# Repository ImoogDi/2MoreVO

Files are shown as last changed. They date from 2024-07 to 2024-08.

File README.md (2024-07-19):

#  2MoreVO
 Eurorack Dual VCO using the public CEM3340/AS3340 chip.

**Table of Contents**

- [Introduction](#intro)
- [Construction Guide](./doc/constructionguide.md)
- [Calibration](./doc/calibration.md)
- [Technical data](#technical-data)
- [References](#references)
- [License](#license)

## Introduction

This eurorack-modul is designed for modular-synthesizers as dual Voltage Controlled Oscillator.  
The oszillators are build around two IC's: <u>AS3340</u>, a clone of that wellknown CEM3340.  
Another benifit is the <u>three cannel VCA: AS3363</u> included to control the modulation-level, waveform output of VCO1 and oscillator-signal fading between VCO1- and VCO2-outputs.  

The '2MoreVO'-PCB's are:  
- one main backplane ('Backplane'), holding all switches, pots, jacks and voltage-references.  
- two VCO-PCB's stacked on the 'Backplane'.  
- one another backplane-PCB ('Backplane_B') hodling the 'three cannel VCA', operational-amp's and the eurorack-connection stacked on the 'Backplane'.   

All parts are common available and DIY-friendly designed, most parts are SMD on the VCO-PCB's.   
(Details see attached pictures)  

- Modul Frontpanel

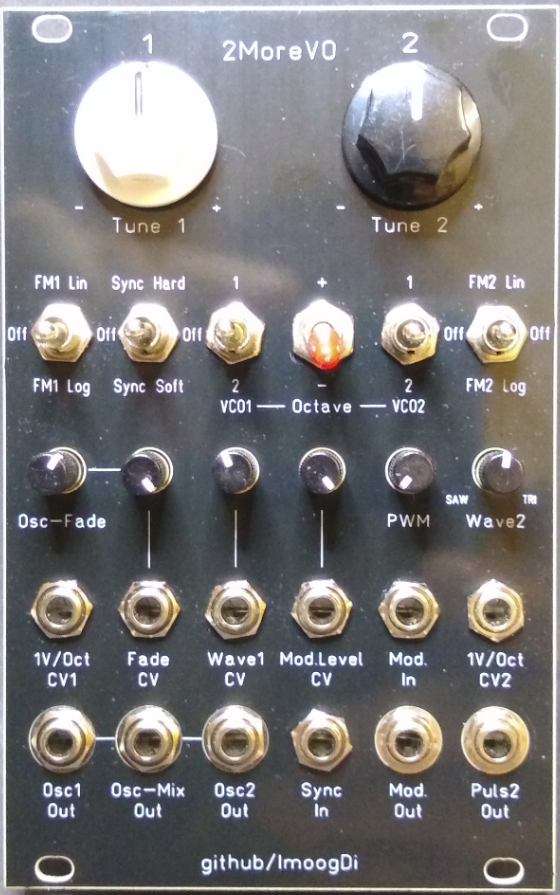
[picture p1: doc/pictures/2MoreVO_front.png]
Modul: 2MoreVO Front


<br>
- Modul Backpanel

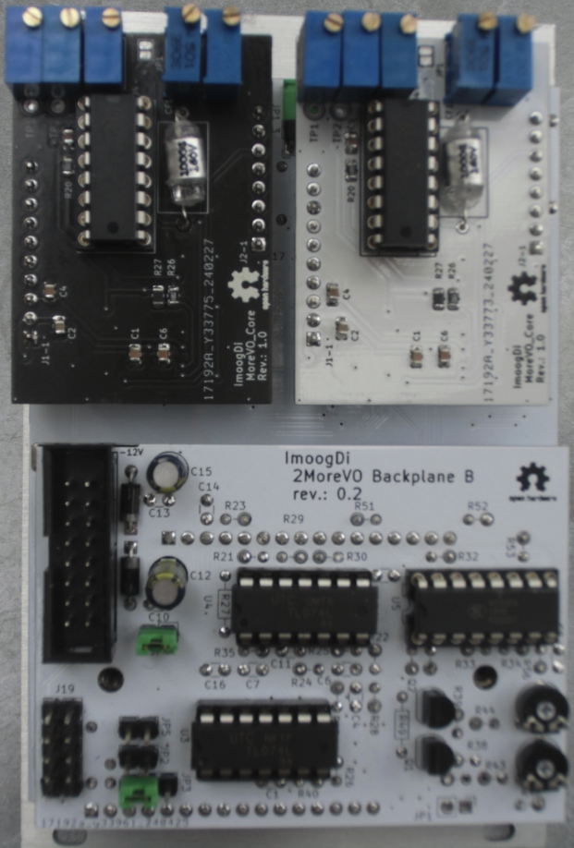
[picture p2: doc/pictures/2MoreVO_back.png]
Modul: 2MoreVO Backside


<br>
- Modul function-blocks

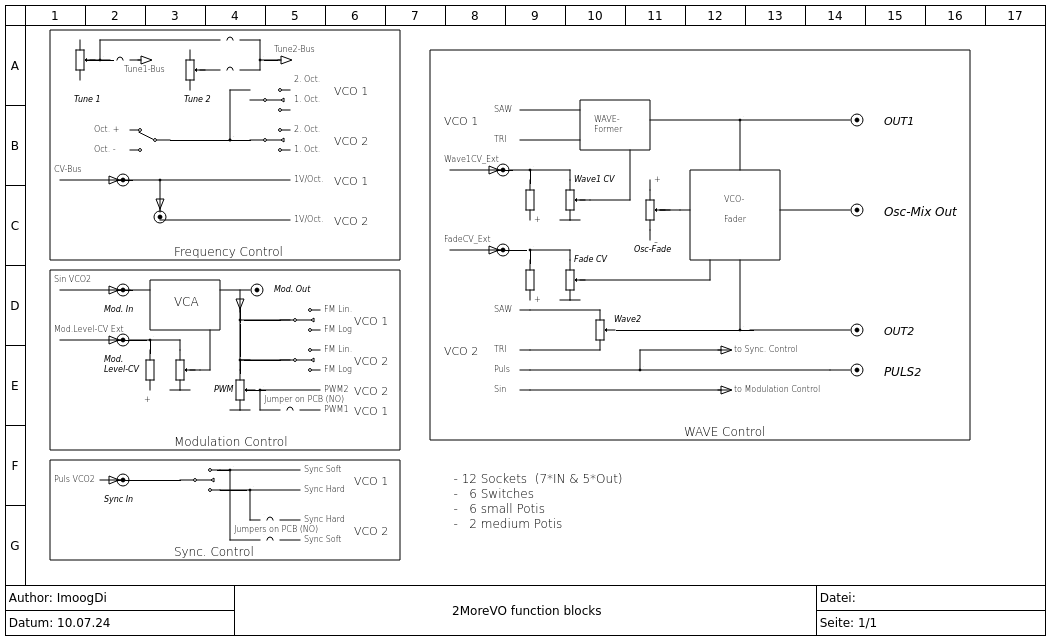
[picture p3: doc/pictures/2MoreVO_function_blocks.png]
Modul: 2MoreVO function blocks


<br>

<hr>
There are twelve 3.5mm jacks available for patching audio- and CV-signals.  

<table>
<tr>
    <th>Jack-Name</th>
    <th>Function</th>
    <th>Comment</th>
    <th>Detail</th>
</tr>
<tr>
    <td>1V/Oct CV1</td>
    <td>CV-input for VCO1 pitch control</td>
    <td>fixed 1Volt/Octave scaling</td>
    <td>This input is normalised with the eurobus Control-Voltage and connected with the '1V/Oct CV2' input.<br>Patch-cabel plugged in breaks the default connection to eurobus CV but the connection to '1V/Oct CV2' is still available.</td>
</tr>
<tr>
    <td>Fade CV</td>
    <td>CV-input for fading oscillator-signals</td>
    <td>The Fading between Osc1- and Osc2-signals on 'Osc-Mix Out' is controlled with this CV</td>
    <td>CV level adjustable between 0 ... max. with 'Fade CV'-pot.<br>works together with 'Osc-Fade'-pot.<hr>Bipolar signal input.</td>
</tr>
<tr>
    <td>Wave1 CV</td>
    <td>CV-input for VCO1 wave-control</td>
    <td>The waveform on 'Osc1 Out' is controlled with this CV</td>
    <td>CV Level adjustable between 0 ... max. with 'Wave1 CV'-pot.<hr>Bipolar signal input.</td>
</tr>
<tr>
    <td>Mod.Level CV</td>
    <td>CV-input for modulation level control</td>
    <td>Control of modulation level on 'Mod Out'</td>
    <td>Modulation Level adjustable between 0 ... max. with 'Mod.Level CV'-pot.<hr>Bipolar signal input.</td>
</tr>
<tr>
    <td>Mod. In</td>
    <td>Modulation signal input</td>
    <td>input for external signals controlling FM(Lin/Log) and PWM on Osc1 and Osc2</td>
    <td>This input is normalised with the sinusoidal-signal from Osc2 if no signal is plugged in.<hr>Bipolar signal input.</td>
</tr>
<tr>
    <td>1V/Oct CV2</td>
    <td>CV-input for VCO2 pitch control</td>
    <td>fixed 1Volt/Octave scaling</td>
    <td>This input is normalised with the '1V/Oct CV1' input.<br>Patch-cabel plugged in breaks the default connection to '1V/Oct CV1'.</td>
</tr>
<tr>
    <td>Osc1 Out</td>
    <td>output for VCO1-oscillator signal</td>
    <td>triangle- to saw-waveform output, morvable manually or with external CV</td>
    <td>Waveform morvable with 'Wave1 CV'-pot and CV-signal.</td>
</tr>
<tr>
    <td>Osc-Mix Out</td>
    <td>output for mixed VCO1-/VCO2-oscillator signal</td>
    <td>mixed signal from Osc1- and Osc2-outputs</td>
    <td>Waveforms fadeable between Osc1- and Osc2-signal outputs.<br>Fading can be done with 'Fade CV'-pot and CV-signal.<br>50%/50% Osc1/2-signal level on 'Osc-Mix Out', if 'Osc-Fade'-pot is in centerposition and no 'Fade CV' is plugged in.</td>
</tr>
<tr>
    <td>Osc2 Out</td>
    <td>output for VCO2-oscillator signal</td>
    <td>saw- to triangle-waveform output, morvable manually</td>
    <td>Waveform morvable with 'Wave2'-pot between saw- and triangle-signal.</td>
</tr>
<tr>
    <td>Sync In</td>
    <td>Sync-signal for VCO1 (optional VCO2)</td>
    <td>this signal can be switched to: 'Sync Hard', ' Sync Soft' or 'Off'</td>
    <td>This input is normalised with the 'Puls2 Out'-signal from VCO2.<br>Patch-cabel plugged in breaks the default connection to 'Puls2 Out'.</td>
</tr>
<tr>
    <td>Mod Out</td>
    <td>output for modulation-signal controllable with 'Mod.Level CV'</td>
    <td>modulation-signal used for 'FMx Lin/Log' and 'PWM'<br>default sinusoidal-signal from VCO2 used for VCO1 modulation</td>
    <td>sinusoidal-signal from VCO2 is available on this output if high impedance connection is used.<hr>optional an external low impedance signal plugged in can overwride the internal modulation.</td>
</tr>
<tr>
    <td>Puls2 Out</td>
    <td>output for puls-signal from VCO2</td>
    <td>output-signal for synchronisation and audio<br>the pulswith is controllable with 'PWM'-pot using the 'Mod Out'-signal</td>
    <td>This output is also internally linked to 'Sync In'.<hr>Bipolar output with +-5.0Volt level.</td>
</tr>
</table>
<br>

There are eight potentiometers with following functions:  

<table>
<tr>
    <th>Pot-Name</th>
    <th>Function</th>
    <th>Comment</th>
    <th>Detail</th>
</tr>
<tr>
    <td>Tune 1</td>
    <td>Pitch for VCO1</td>
    <td>default pitch in center-position</td>
    <td>tuning-range +-2 octaves.</td>
</tr>
<tr>
    <td>Tune 2</td>
    <td>Pitch for VCO2</td>
    <td>default pitch in center-position</td>
    <td>tuning-range +-2 octaves.</td>
</tr>
<tr>
    <td>Osc-Fade</td>
    <td>manually fading between Osc1- and Osc2-signals on 'Osc-Mix Out'</td>
    <td>works as CV offset for the 'Fade CV'-signal</td>
    <td>pot to CCW: Osc2-signal output.<br>pot to CW: Osc1-signal output.<br>pot to centerposition: equal level output.</td>
</tr>
<tr>
    <td>Fade CV</td>
    <td>CV Level amount pot for fading between Osc1- and Osc2-signals on 'Osc-Mix Out'</td>
    <td>works together with 'Osc-Fade' for fading Osc1/2-signals</td>
    <td>CV Level adjustable between 0 ... max.</td>
</tr>
<tr>
    <td>Wave1 CV</td>
    <td>CV Level amount pot for Osc1 waveform-selection on 'Osc1 out'</td>
    <td>manually selection of waveform is possible if no CV-signal is plugged in</td>
    <td>CV Level adjustable between 0 ... max.</td>
</tr>
<tr>
    <td>Mod.Level CV</td>
    <td>CV Level amount pot for modulation control</td>
    <td>manually modulationlevel control is possible if no CV-signal is plugged in</td>
    <td>CV Level adjustable between 0 ... max.</td>
</tr>
<tr>
    <td>PWM</td>
    <td>pulswith pot to control amount of PWM</td>
    <td>the modulation-signal on 'Mod Out' is used for PWM</td>
    <td>PWM amount adjustable between 0 ... max.<br>Pulswith is 50% on 'Puls2 Out' if pot is in CCW-position (set to 0).</td>
</tr>
<tr>
    <td>Wave2</td>
    <td>waveform selection pot for Osc2-signal</td>
    <td>manually morving between saw- and triangle-signal</td>
    <td>pot to CCW: SAW-signal.<br>pot to CW: Triangle-signal.<br>pot to centerposition: mixed signal.</td>
</tr>
</table>
<br>

There are six switches to control the behaviour of signals.  

<table>
<tr>
    <th>Switch</th>
    <th>Function</th>
    <th>Comment</th>
    <th>Detail</th>
</tr>
<tr>
    <td>FM1-switch</td>
    <td>switch for VCO1 FM modulation using signal on 'Mod Out'</td>
    <td>FM controll for VCO1</td>
    <td>FM1 Lin := Linear FM modulation.<br>Off := function off.<br>FM1 Log := Logarithmic FM modulation.</td>
</tr>
<tr>
    <td>Sync-switch</td>
    <td>switch for VCO1 Hard- or Soft-synchronisation with puls-signal from VCO2</td>
    <td>switched synchronisation-signal from 'Puls2 Out'</td>
    <td>Sync Hard := hard synced to VCO2.<br>Off := sync. function off.<br>Sync Soft := soft synced to VCO2.</td>
</tr>
<tr>
    <td>VCO1 Octave-switch</td>
    <td>switch for VCO1 pitch setting</td>
    <td>octaves up or down depending on 'Octave switch + or -'</td>
    <td>1 := one octave (up/down).<br>2 := two octaves (up/down).</td>
</tr>
<tr>
    <td>Octave up/down switch</td>
    <td>switch for VCO1- and VCO2-switched pitchcontrol</td>
    <td>selecting pitch up or down for VCO1 and VCO2</td>
    <td>+ :=  pitch up.<br>- := pitch down.</td>
</tr>
<tr>
    <td>VCO2 Octave-switch</td>
    <td>switch for VCO2 pitch setting</td>
    <td>octaves up or down depending on 'Octave switch + or -'</td>
    <td>1 := one octave (up/down).<br>2 := two octaves (up/down).</td>
</tr>
<tr>
    <td>FM2-switch</td>
    <td>switch for VCO2 FM modulation using signal on 'Mod Out'</td>
    <td>FM controll for VCO2</td>
    <td>FM1 Lin := Linear FM modulation.<br>Off := function off.<br>FM1 Log := Logarithmic FM modulation.</td>
</tr>
</table>
<br>
<hr>

## Technical data

- size:  
  width: 16HP  
  depth: 45mm

- power:  
    5Volt, 0 mA  
  +12Volt, 60mA  
  -12Volt, 60mA  

- frequency range: 20Hz to 20kHz.
- frequency CV scale: 1V/Oct on '1V/Oct CV1'- and '1V/Oct CV2'-inputs.
- frequency pot tuning range: +-2 Octaves.
- frequency switchable pitch range: plus or minus 1 or 2 octaves for oscillator 1/2.
- signal inputs, DC-coupled signal path.
- signal outputs, DC-coupled signal path.
- signal input impedance: > 50kOhm.
- signal output impedance: 500 Ohm.
- expandable with more '2MoreVO' dual-oscillator('s) used in master-/slave-configuration.

## References

* [electric druid, Single VCA crossfader](https://electricdruid.net/single-vca-crossfader/)
* [Tuning the AS3340](https://www.alfarzpp.lv/eng/sc/Tuning%20the%20AS3340.pdf)

## License
> Hardware:cc by-nc-sa 4.0  ([details](https://creativecommons.org/licenses/by-nc-sa/4.0/))

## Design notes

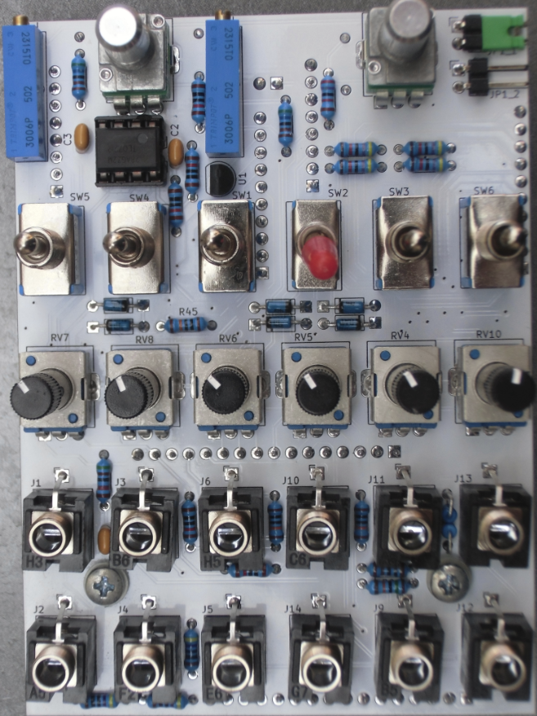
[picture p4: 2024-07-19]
doc/pictures/Backplane_top_mounted.png

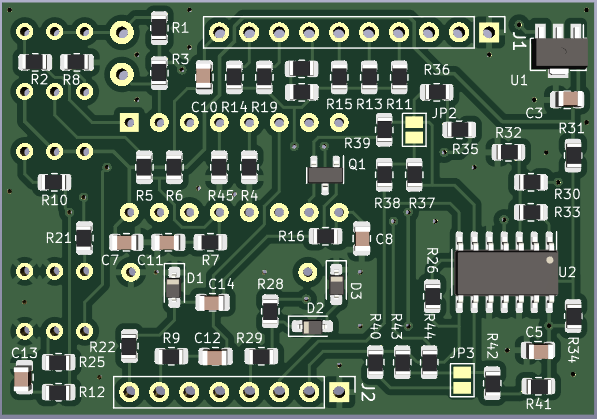
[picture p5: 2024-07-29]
doc/pictures/MoreVO_Core_bot_smds_only.png

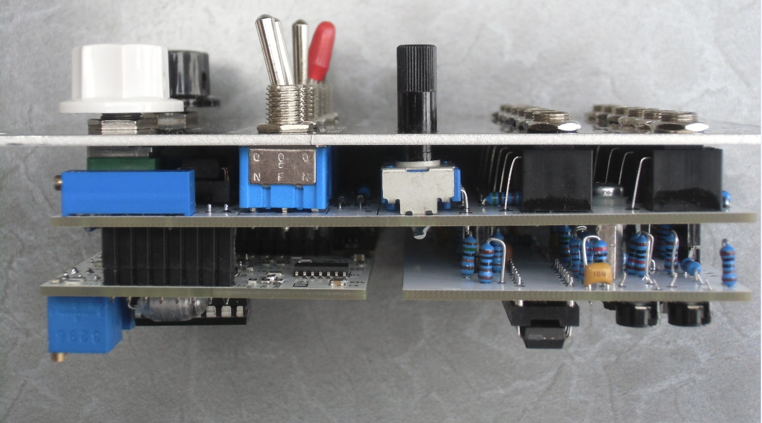
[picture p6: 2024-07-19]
doc/pictures/2MoreVO_left.png

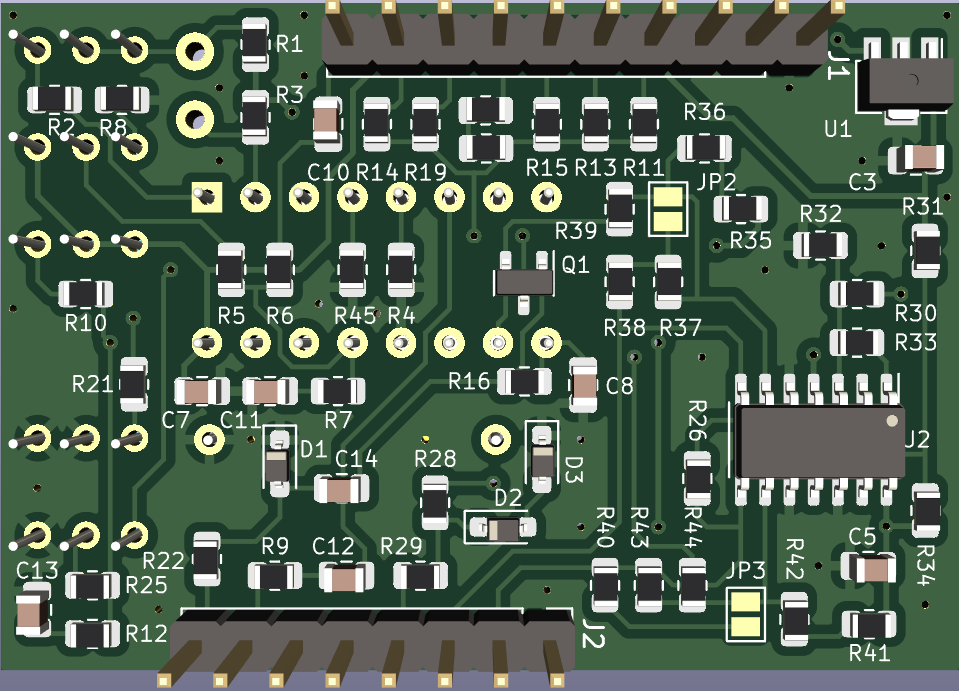
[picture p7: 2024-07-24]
doc/pictures/MoreVO_Core_PCB_bot.png

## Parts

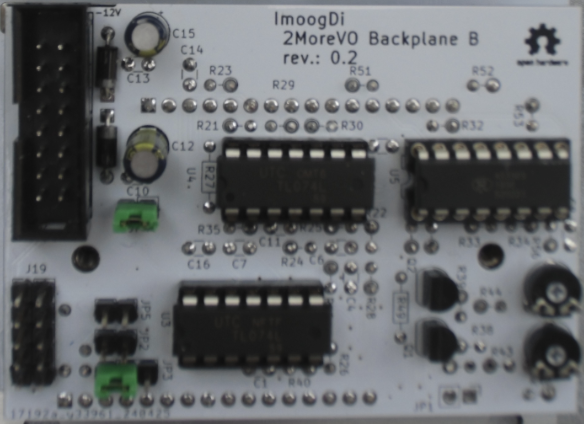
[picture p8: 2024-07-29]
doc/pictures/Backplane_B_bot_parts_mounted.png

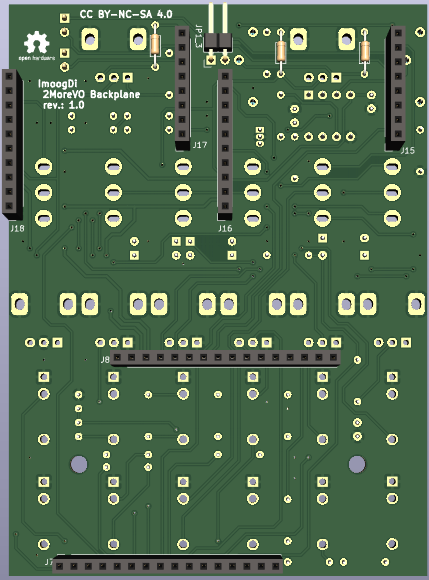
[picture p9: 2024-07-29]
doc/pictures/Backplane_bot_parts_mounted.png

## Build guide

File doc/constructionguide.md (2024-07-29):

#  2MoreVO
 Construction of CEM/AS3340 dual analog VCO eurorack-modul.

**Table of Contents**

- [Preconditions](#preconditions)
- [Construction](#construction)
- [First Switchon](#firstswitchon)
- [License](#license)

## Preconditions

- All PCB-Boards must be available:  
    1. Two 'MoreVO_Core'- PCB's. 
    2. One 'Backplane' - PCB. 
    3. One 'Backplane B' - PCB. 
- All BOM-parts must be available for PCB-Board 'MoreVO_Core', 'Backplane' and 'Backplane B' (see BOM-files: [MoreVO_Core](./../hw/MoreVO_Core/bom/MoreVO_Core.html) and [Backplane](./../hw/bom/2MoreVO_backplane.html)).
- The frontpanel is required for aligned soldering all pots, jacks and switches on PCB-Board 'Backplane'.

## Construction

### PCB-Board: 'MoreVO_Core' (two of them)

>#### 'MoreVO_Core' back side smd-parts (start soldering here!) [back side parts](./pictures/MoreVO_Core_PCB_bot.png)

> start soldering smd-parts on back side of Board: 'MoreVO_Core'.  

>- place all SMD resistors and capacitors to the back side. Watch the rigth alignment.
>- place all SMD diodes to the back side. Watch the rigth orientation and alignment.
>- place the LDO voltage-regulator U1 to the back side. Watch the rigth orientation and alignment.
>- place the transistor Q1 to the back side. Watch the rigth orientation and alignment.
>- place the quad opamp U2 to the back side. Watch the rigth orientation and alignment.
>- solder all parts on back side (reflow or by hand).
>- at least 'MoreVO_Core'-PCB back side should look like: [MoreVO_Core back side smd-parts (rev.: 1.1)](./pictures/MoreVO_Core_bot_smds_only.png) 

>#### 'MoreVO_Core' top side smd-parts [top side parts](./pictures/MoreVO_Core_PCB_top.png)

> continue soldering smd-parts on top side of Board: 'MoreVO_Core'.  

>- place all SMD resistors and capacitors to the top side. Watch the rigth alignment.
>- solder all parts on top side (by hand).
>- at least 'MoreVO_Core'-PCB top side should look like: [MoreVO_Core top side smd-parts (rev.: 1.1)](./pictures/MoreVO_Core_top_smds_only.png) 

>#### 'MoreVO_Core' <u>M</u>ounting<u>T</u>hrough<u>H</u>ole-parts [MTH-parts](./pictures/MoreVO_Core_PCB_top.png)

> continue soldering MTH-parts on back side of Board: 'MoreVO_Core'.  
>- fit the 10-position, 1 row header to the back side and solder it at the top side.  
>- fit the  8-position, 1 row header to the back side and solder it at the top side.  

> continue soldering MTH-parts on top side of Board: 'MoreVO_Core'.  
>- place one DIP16 socket at U4-position on top side. Watch the rigth orientation and solder it on back side.  
>- place all pots (RV1...RV5) on top side. Watch the rigth values and orientation and solder them on back side.  
>- at least place styrene capacitor CF1 on top side and solder it on back side.  

### PCB-Board: 2MoreVO 'Backplane'

>#### 'Backplane' back side MTH-parts (start soldering here!) [back side parts](./pictures/Backplane_bot_parts_mounted.png)

> start soldering MTH-parts on back side of Board: 'Backplane'.  

>- place all resistors to the back side and solder them on top side.
>- fit the two 10-position, 1 row pin-sockets to the back side and solder them at the top side.  
>- fit the two  8-position, 1 row pin-sockets to the back side and solder them at the top side.  
>- fit the two 16-position, 1 row pin-sockets to the back side and solder them at the top side.  
>- at least place jumper J1_3 to the back side and solder it on top side.  

>#### 'Backplane' top side MTH-parts [top side parts](./pictures/Backplane_top_parts_mounted.png)

> continue soldering MTH-parts on top side of Board: 'Backplane'.  

>- place all resistors to the top side and solder them on back side. Be aware two of them mounted vertically.  
>- place all capacitors to the top side and solder them on back side.  
>- place all diodes to the top side. Watch the rigth orientation and solder them on back side.  
>- place the shunt regulator U1 to the top side. Be sure to mount it close as possible to the PCB. Watch the rigth orientation and solder it on back side.  
>- place one DIP8 socket at U2-position on top side. Watch the rigth orientation and solder it on back side.  
>- place two jumpers J1_1 and J1_2 on top side and solder them on back side.  
>- place two pots (RV1 and RV12) on top side. Watch the rigth orientation and solder them on back side.  
>- the currently mounted '2MoreVO'-backplane top side should look like: [2MoreVO backplane top side (rev.: 1.0)](./pictures/Backplane_top_parts_mounted.png) 

>- **All following parts have to be aligned to the frontpanel and not yet soldered **
>- fit that snapin-potentiometers PV4,PV5,PV6,PV7,PV8 and PV10 on PCB top side.
>- fit that snapin-potentiometers PV2 and PV3 on PCB top side.
>- fit that switches SW1,SW3,SW4,SW5 and SW6 on PCB top side. Must be ON-OFF-ON type with three positions.
>- fit that switch SW2 on PCB top side. Must be ON-ON type with two positions.
>- fit all twelve jacks on PCB top side.
>- place the **frontpanel** on top side parts and **align** them.
>- check alignment and distance to the frontpanel, see: [alignment](./pictures/2MoreVO_left.png)
>- use nuts for the jacks, switches and pots to fix that frontpanel to the PCB-parts.
>- now solder all parts on back side and make sure everything is still aligned.
>- mount two 10mm spacer with 3mm screws and plastic washer on the backplane.
>- at least the '2MoreVO backplane' without mounted frontpanel should look like: [backplane mounted parts](./pictures/Backplane_top_mounted.png) 

### PCB-Board: 2MoreVO 'Backplane B'

>#### 'Backplane B' top side MTH-parts (start soldering here!) [top side parts](./pictures/Backplane_B_top.png)

> start soldering MTH-parts on top side of Board: 'Backplane B'.  

>- place all resistors to the top side. **Important:** vertical mounted resistors have to be bend as close as possible to there resistore-cases (see: [vertical resistors mounted](./pictures/Backplane_spacer.png)). solder them on back side.
>- place all capacitors to the top side and solder them on back side.  
>- fit the two 16-position, 1 row header to the top side and solder them at the back side.  
>- at least 'Backplane B' top side should look like: [Backplane B top side parts (rev.: 1.0)](./pictures/Backplane_B_top_parts_mounted.png) 

>#### 'Backplane B' back side MTH-parts [back side parts](./pictures/Backplane_B_bot_parts.png)

> continue soldering MTH-parts on back side of Board: 'Backplane B'.  

>- place the electrolytic capacitors (C12/C15) to the back side. Watch the rigth orientation and solder them on top side.  
>- place the ceramic capacitors to the back side. solder them on top side.  
>- place all diodes to the back side. Watch the rigth orientation and alignment. solder them on top side.  
>- place the two transistors Q1 and Q2 to the back side. Watch the rigth orientation and solder them on top side.  
>- place the two pots to the back side. Watch the rigth orientation and solder them on top side.  
>- place the two pin- and three pin-jumpers to the back side and solder them on top side.  
>- place the 5-position, 2 row header to the back side and solder it at the top side.  
>- place the 8-position, 2 row header to the back side and solder it at the top side.  
>- place two DIP14 sockets at U3/U4-position on back side. Watch the rigth orientation and solder them on top side.  
>- place one DIP16 socket at U5-position on back side. Watch the rigth orientation and solder it on top side.  
>- at least 'Backplane B' back side should look compareable with this: (IC's not yet mounted) [Backplane B back side parts (rev.: 1.0)](./pictures/Backplane_B_bot_parts_mounted.png) 

## First Switchon
 Preconditions:

- Unmount any IC from the sockets on '2MoreVO Backplane B' if not already done.
- Push IC U2 (TL072) into the DIP-socket on '2MoreVO Backplane'.
- Push the '2MoreVO Backplane B' into the pin-sockets of '2MoreVO Backplane'.
- connect one 16pin buscabel between eurorack-bus and the '2MoreVO Backplane B' (watch the alignment of Pin1 := -12V).
- The two 'MoreVO_Core'-boards aren't yet mounted.
- The frontpanel isn't yet mounted.

 Action Step1:

- Switch **on** the eurorack-case power.
- Measure voltages at points:  

<table>
<tr>
    <th>2MoreVO Board</th>
    <th>measuring point</th>
    <th>measured voltages</th>
    <th>remark</th>
</tr>
<tr>
    <td>Backplane (top side)</td>
    <td>IC U2 Pin8</td>
    <td>+12 Volt</td>
    <th></th>
</tr>
<tr>
    <td>Backplane (top side)</td>
    <td>IC U2 Pin4</td>
    <td>-12 Volt</td>
    <th></th>
</tr>
<tr>
    <td>Backplane (back side)</td>
    <td>J16 and J18 Socket-Pin2</td>
    <td>+12 Volt</td>
    <th>Plus eurorack-power for 'MoreVO_Core' 1 and 2</th>
</tr>
<tr>
    <td>Backplane (back side)</td>
    <td>J16 and J18 Socket-Pin3</td>
    <td>-12 Volt</td>
    <th>Minus eurorack-power for 'MoreVO_Core' 1 and 2</th>
</tr>
<tr>
    <td>Backplane B (back side)</td>
    <td>Testpoint +2V</td>
    <td>range: +1.5 to +2.5 Volt</td>
    <th>will be adjusted in calibration-procedure</th>
</tr>
<tr>
    <td>Backplane B (back side)</td>
    <td>Testpoint -2V</td>
    <td>range: -1.5 to -2.5 Volt</td>
    <th>will be adjusted in calibration-procedure</th>
</tr>
<tr>
    <td>Backplane B (back side)</td>
    <td>U3 and U4 DIP14-Pin14</td>
    <td>+12 Volt</td>
    <th>Plus eurorack-power</th>
</tr>
<tr>
    <td>Backplane B (back side)</td>
    <td>U3 and U4 DIP14-Pin7</td>
    <td>-12 Volt</td>
    <th>Minus eurorack-power</th>
</tr>
<tr>
    <td>Backplane B (back side)</td>
    <td>U5 DIP16-Pin16</td>
    <td>+12 Volt</td>
    <th>Plus eurorack-power</th>
</tr>
<tr>
    <td>Backplane B (back side)</td>
    <td>U5 DIP16-Pin8</td>
    <td>-12 Volt</td>
    <th>Minus eurorack-power</th>
</tr>
</table>

 Action Step2:

- Switch **off** the eurorack-case power.
- Mount the frontpanel on '2MoreVO Backplane'.
- Insert all IC's on '2MoreVO Backplane B'. Watch the rigth orientation.
- Insert the two 'MoreVO_Core'-boards into the pin-sockets on '2MoreVO Backplane' intended for VCO1 and VCO2. Don't yet insert the CEM3340/AS3340 into there sockets.

 Action Step3:

- Switch **on** the eurorack-case power.
- Measure voltages at points:  

<table>
<tr>
    <th>2MoreVO Board</th>
    <th>measuring point</th>
    <th>measured voltages</th>
    <th>remark</th>
</tr>
<tr>
    <td>both MoreVO Core Boards (top side)</td>
    <td>U4 DIP16-Pin16</td>
    <td>+10 Volt DC</td>
    <th>+- 1% voltage accuracy</th>
</tr>
<tr>
    <td>both MoreVO Core Boards (top side)</td>
    <td>U4 DIP16-Pin3</td>
    <td>-5 Volt DC</td>
    <th>less then +- 2% voltage accuracy</th>
</tr>
</table>

- Switch **off** the eurorack-case power.

 Result:

If any measurement is out of range check the boards and repeat the required steps.

 Postconditions:

- push the IC's:=CEM3340 or AS3340 into the socket on the two 'MoreVO Core'-boards. Watch the rigth orientation.
- Calibration of the boards is required and defined in the calibration-procedure.  

- at least the '2MoreVO'-board back side should look like: [2MoreVO back side](./pictures/2MoreVO_back.png) 

## License
> Hardware:cc by-nc-sa 4.0

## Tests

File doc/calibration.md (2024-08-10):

#  2MoreVO
 Calibration of CEM/AS3340 dual analog VCO eurorack-modul.

## Preconditions
 Required or recommended tools are:

- High precision voltage meter.
- Frequency meter.
- MoreVO_Core breadboard with 5.0V and 8.0V voltage references (if available).
- Eurorack for power (+12V/-12V) and keyboard-CV.
- 16pin Eurorack cable for modul-connection to the rack-bus.
- patchcables for modular synthesizers.
- all PCB's have to be mounted.

## Calibration

**Table of Contents**

- [Reference-voltage-Adjustment](#refvoltage_adjustment)
- [MoreVO_Core-Adjustments](#morevo_core_adjustments)
- [VCO2 sinusodial output-Adjustments](#sinusodial_adjustment)
- [Final check](#final_check)
- [License](#license)

<hr> 

### Reference-voltage-Adjustment on '2MoreVO Backplane
Reference-voltage-adjustment is done with precision trimmers 'RV1' and 'RV12' on the 'Backplane'.  

> Backplane top side precision trimmer **RV1** and **RV12**  
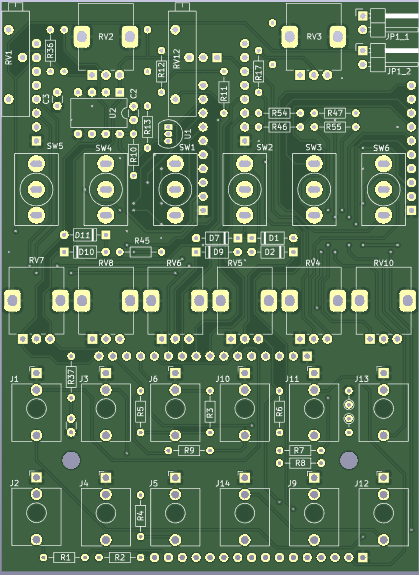
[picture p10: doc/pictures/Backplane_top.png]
Backplane top side overview
  

Measurement-points are **+2V** and **-2V** on 'Backplane B'.

> Backplane B measurment-points  
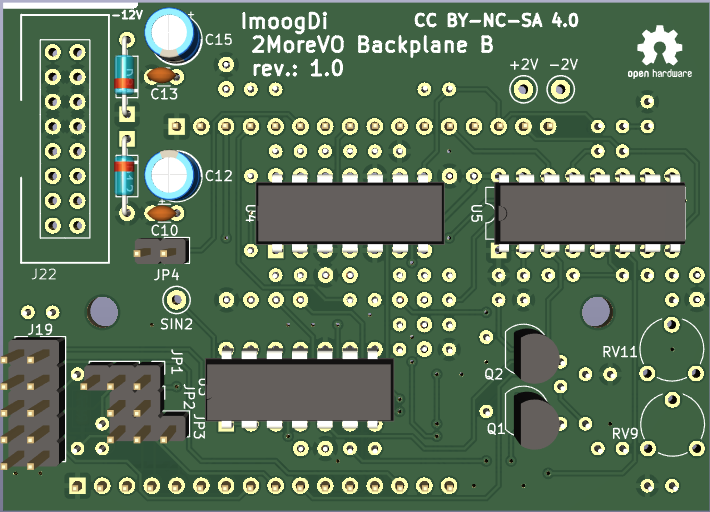
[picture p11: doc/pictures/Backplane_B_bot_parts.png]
Backplane B bottom side overview
  
<br>
<table>
<tr>
    <th>measuring point</th>
    <th>adjustment on</th>
    <th>measured voltage</th>
    <th>remark</th>
</tr>
<tr>
    <td>'Backplane B' +2V (back side)</td>
    <td>'Backplane' RV1 (top side)</td>
    <td>+2000 mVolt</td>
    <td>adjust as close as possible to nominal value.</td>
</tr>
<tr>
    <td>'Backplane B' -2V (back side)</td>
    <td>'Backplane' RV12 (top side)</td>
    <td>-2000 mVolt</td>
    <td>adjust as close as possible to nominal value.</td>
</tr>
</table>

<hr> 

### 'MoreVO-Core'-Adjustment for true 1V/octave-range

For AS3340 calibration details see also URL: [AS3340 tuning](https://www.alfarzpp.lv/eng/sc/Tuning%20the%20AS3340.pdf)

If the MoreVO_Core breadboard (with 5.0V and 8.0V voltage references) is available, all required adjustments on 'MoreVO_Core's are done on that breadboard, else the '2MoreVO'-moduls must be stacked in the 'Backplane' and calibrated in the eurorack.

> MoreVO_Core precision pot's **RV1 ... RV5** location  
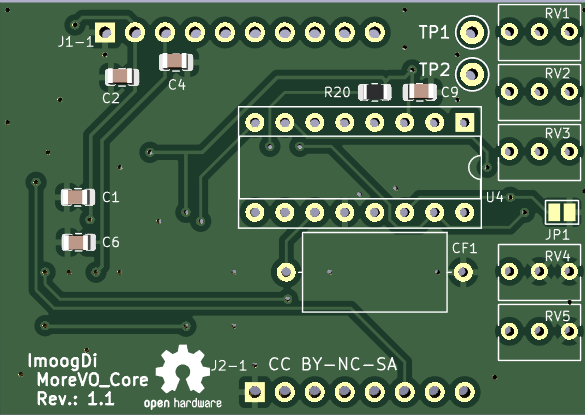
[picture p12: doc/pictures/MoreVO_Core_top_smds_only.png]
MoreVO_Core precision pot's
  

#### 'MoreVO_Core' adjustment on breadboard  

Preparation:

- Connect GND to header J1-1.  
- Connect +12Volt to header J1-2.  
- Connect -12Volt to Header J1-3.  

>Be carefull and check that connections.  
>Switch on powersupply and **warm up** that board at least for 30minutes.

<table>
<tr>
    <th>Step<br> Nr</th>
    <th>preparation</th>
    <th>action</th>
    <th>remark</th>
</tr>
<tr>
    <td>1</td>
    <td>Connect mV meter between TP1 and TP2</td>
    <td>Trim 'TEMPCO ADJ' pot (RV1) until:<br>Voltage is 0.0mV</td>
    <td></td>
</tr>
<tr>
    <td>2</td>
    <td>Close (short) jumper JP1 on top-side of the board</td>
    <td>Trim 'REF PITCH C6' pot (RV2) until:<br>Pitch is 1046.5 Hertz (C6)</td>
    <td>measured on SAW_Out (J2-2)</td>
</tr>
<tr>
    <td>3</td>
    <td>Apply +5.000Volt DC on 'Tune'-input (J1-4)</td>
    <td>Trim 'REFIND C6' pot (RV3) until:<br>Pitch is again 1046.5 Hertz (C6)</td>
    <td>measured on SAW_Out (J2-2)</td>
</tr>
<tr>
    <td>4</td>
    <td>Apply 0.000Volt DC on 'Tune'-input (J1-4)</td>
    <td>Trim 'SCALE ADJ' pot (RV4) until:<br>Pitch is 32.7 Hertz</td>
    <td>measured on SAW_Out (J2-2)</td>
</tr>
<tr>
    <td>5</td>
    <td>Apply +8.000V DC on 'Tune'-input (J1-4)</td>
    <td>Trim 'HIGH FREQUENCY ADJUST' pot (RV5) until:<br>Pitch is 8372.0 Hertz</td>
    <td>measured on SAW_Out (J2-2)</td>
</tr>
</table>

Repead above steps for the second 'MoreVO_Core'.

After calibration put both 'MoreVO_Core' boards into the '2MoreVO' backplane.

<hr>

#### 'MoreVO_Core' adjustment stacked on 2MoreVO backplane  

Preparation:

- Set 'Tune 1'and 'Tune 2' pot's to center-position.
- Set all <u>three-position switches</u> to center-position: **Off**.
- Set 'Wave1 CV' pot to: **CCW** (Saw).
- Set 'Wave2' pot to: **CCW** (Saw).
- Connect the '2MoreVO'-modul with 16pin Eurorack cable to the rack-bus.
- Connect patch-cabel into jack '1V/Oct CV1' on 2MoreVO-modul to get that 1V/octave CV voltage from keyboard.
- Switch on Eurorack power.
- Check voltages at pin J1-4 on both MoreVO_Core's to be zero. If required adjust that related tune-pots 'Tune 1' and 'Tune 2' to get at close as possible to zero volt on pins J1-4.

>**warm up** that '2MoreVO'-modul at least for 30minutes.

> '2MoreVO' mounted MoreVO_Core's  
back mounted MoreVO_Core's  

Start calibration with one 'MoreVO_Core' and repeat it with the second one in following steps:

<table>
<tr>
    <th>Step<br> Nr</th>
    <th>preparation</th>
    <th>action</th>
    <th>remark</th>
</tr>
<tr>
    <td>1</td>
    <td>Connect mV meter between TP1 and TP2</td>
    <td>Trim 'TEMPCO ADJ' pot (RV1) until:<br>Voltage is 0.0mV</td>
    <td>measured and adjusted at: VCO1 and VCO2.</td>
</tr>
<tr>
    <td>2</td>
    <td>Close (short) jumper JP1 on top-side of the board</td>
    <td>Trim 'REF PITCH C6' pot (RV2) until:<br>Pitch is 1046.5 Hertz (C6)</td>
    <td>measured at:<br>'Osc1 Out' for VCO1.<br>'Osc2 Out' for VCO2.</td>
</tr>
<tr>
    <td>3</td>
    <td>Apply +5.000Volt CV on '1V/Oct CV1'-input pressing pitch-key 'C6' on the keyboard</td>
    <td>Trim 'REFIND C6' pot (RV3) until:<br>Pitch is again 1046.5 Hertz (C6)</td>
    <td>measured at:<br>'Osc1 Out' for VCO1.<br>'Osc2 Out' for VCO2.</td>
</tr>
<tr>
    <td>4</td>
    <td>Apply 0.000Volt CV on '1V/Oct CV1'-input with disconnected keyboard CV-voltage.<br>patch-cabel plugged out at keyboard side.</td>
    <td>Trim 'SCALE ADJ' pot (RV4) until:<br>Pitch is 32.7 Hertz</td>
    <td>measured at:<br>'Osc1 Out' for VCO1.<br>'Osc2 Out' for VCO2.</td>
</tr>
<tr>
    <td>5</td>
    <td>Plugin keyboard patch-cabel again.<br>Apply +8.000V DC on '1V/Oct CV1'-input pressing pitch-key 'C9' on the keyboard.</td>
    <td>Trim 'HIGH FREQUENCY ADJUST' pot (RV5) until:<br>Pitch is 8372.0 Hertz</td>
    <td>measured at:<br>'Osc1 Out' for VCO1.<br>'Osc2 Out' for VCO2.</td>
</tr>
</table>

Repead above steps for the second 'MoreVO_Core'.

**1V/Octave calibration done**.

<hr> 

### VCO2 sinusodial-Adjustment

Preparation:

- patch-cabel plugged into jack 'Mod Out' and to any audio-input or waveform-display device.
- pot 'ModLevel CV' set to position: **CW**.
- switch on eurorack-power.

The waveform is adjusted with pot's RV9 (level) and RV11 (offset) on 'Backplane B'.

<table>
<tr>
    <th>Step<br> Nr</th>
    <th>action</th>
    <th>remark</th>
</tr>
<tr>
    <td>1</td>
    <td>Adjust signal-offset with offset-pot: 'RV11'</td>
    <td></td>
</tr>
<tr>
    <td>2</td>
    <td>Adjust sinusodial-waveform with level-pot: 'RV9'</td>
    <td></td>
</tr>
<tr>
    <td></td>
    <td></td>
    <td>repead steps:1 and 2 to get the best result</td>
</tr>
</table>

At least the output signal should look like the following waveform:
> VCO2 sinusodial output on 'Mod Out'  
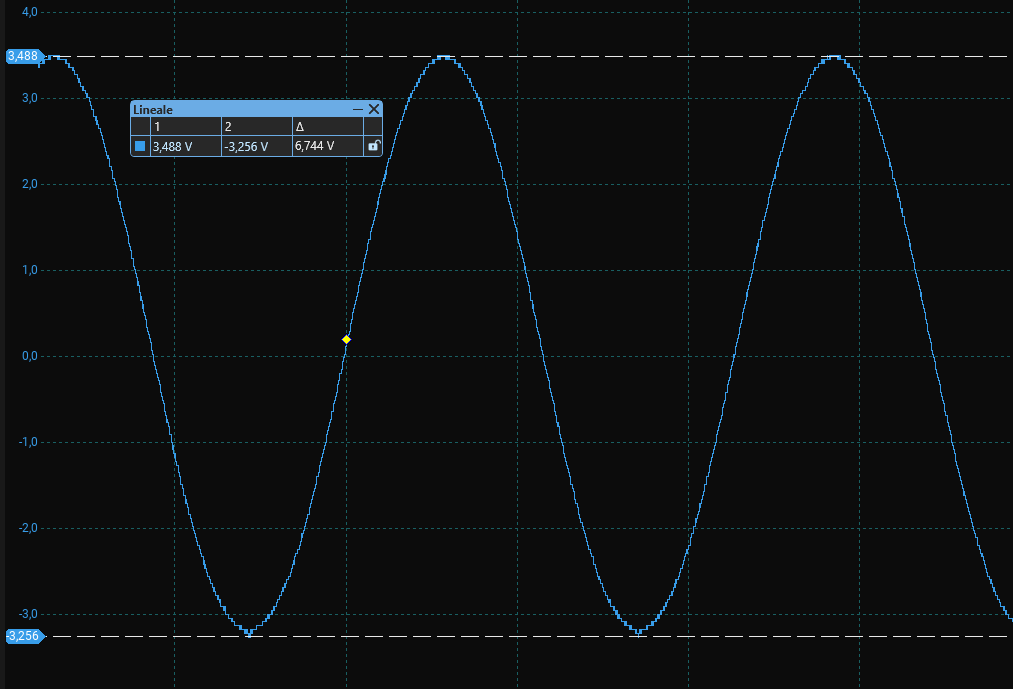
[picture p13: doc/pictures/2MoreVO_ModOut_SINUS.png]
VCO2 sinusodial output


<hr> 

### Final check

Preconditions:

- Jumper J4 on 'Backplane B' must be closed to getting the 1V/Octave CV-voltage from euro-bus.
- Set all <u>three-position switches</u> to center-position: **Off**.
- Modul '2MoreVO' placed into eurorack connected to the bus.
- Eurorack power switched on and warmed up at least for 30 minutes.

<table>
<tr>
    <th>Step<br> Nr</th>
    <th>action</th>
    <th>result</th>
    <th>remark</th>
</tr>
<tr>
    <td>1</td>
    <td>Set pot's 'Tune 1/2' to full CCW position</td>
    <td>measure current pitches on 'Osc1 Out' and 'Osc2 Out'</td>
    <td>remember currently measured pitch-values.</td>
</tr>
<tr>
    <td>2</td>
    <td>Set pot's 'Tune 1/2' to full CW position</td>
    <td>measure current pitches on 'Osc1 Out' and 'Osc2 Out'</td>
    <td>the pitches should be 4 octaves above the values measured in Step:1.</td>
</tr>
<tr>
    <td>3</td>
    <td>Set pot's 'Tune 1/2' to center position</td>
    <td>measure current pitches on 'Osc1 Out' and 'Osc2 Out'</td>
    <td>the pitches should be approximately 2 octaves above the values measured in Step:1.</td>
</tr>
<tr>
    <td>4</td>
    <td>Set switch 'Octave' to '+' and <br>switches 'VCO1'-Octave-'VCO2' to '1'</td>
    <td>measured pitches must be one octave above the 'Off' position</td>
    <td>measured or audible on 'Osc1 Out' and 'Osc2 Out'.</td>
</tr>
<tr>
    <td>5</td>
    <td>Set switch 'Octave' to '+' and <br>switches 'VCO1'-Octave-'VCO2' to '2'</td>
    <td>measured pitches must be two octaves above the 'Off' position</td>
    <td>measured or audible on 'Osc1 Out' and 'Osc2 Out'.</td>
</tr>
<tr>
    <td>6</td>
    <td>Set switch 'Octave' to '-' and <br>switches 'VCO1'-Octave-'VCO2' to '1'</td>
    <td>measured pitches must be one octave below the 'Off' position</td>
    <td>measured or audible on 'Osc1 Out' and 'Osc2 Out'.</td>
</tr>
<tr>
    <td>7</td>
    <td>Set switch 'Octave' to '-' and <br>switches 'VCO1'-Octave-'VCO2' to '2'</td>
    <td>measured pitches must be two octaves below the 'Off' position</td>
    <td>measured or audible on 'Osc1 Out' and 'Osc2 Out'.</td>
</tr>
<tr>
    <td>8</td>
    <td>Set all switches to 'Off' and<br> the VCO's to be in tune with pot's 'Tune 1/2'.<br>Play octave-steps on the keyboard.</td>
    <td>check the VCO-pitches to be in tune over the octaves.</td>
    <td>measured or audible on 'Osc1 Out' and 'Osc2 Out'.</td>
</tr>
<tr>
    <td>9</td>
    <td>Tune pot 'Osc-Fade' from CCW to CW and backwards</td>
    <td>Fading between Osc1- and Osc2-Output waveform must be possible</td>
    <td>measured or audible on 'Osc-Mix Out'.</td>
</tr>
<tr>
    <td>10</td>
    <td>Tune pot 'Wave1 CV' from CCW to CW and backwards</td>
    <td>Changing between triangle- and saw-waveform must be possible</td>
    <td>measured or audible on 'Osc1 Out'.</td>
</tr>
<tr>
    <td>11</td>
    <td>Tune pot 'Wave2' from CCW to CW and backwards</td>
    <td>Changing between triangle- and saw-waveform must be possible</td>
    <td>measured or audible on 'Osc2 Out'.</td>
</tr>
<tr>
    <td>12</td>
    <td>Tune pot 'Mod.Level CV' from CCW to CW and backwards</td>
    <td>Sinusodial signal-level must change on 'Mod Out'</td>
    <td>measured or audible on 'Mod Out'.</td>
</tr>
<tr>
    <td>13</td>
    <td>Set pot 'Mod.Level CV' to CW and tune pot 'PWM' to CW and backwards</td>
    <td>Pulswith must change on 'Puls2 Out'</td>
    <td>measured or audible on 'Puls2 Out'.</td>
</tr>
<tr>
    <td>14</td>
    <td>Set switch 'FM1 Lin/Log' to 'FM1 Lin' and detune VCO2 against VCO1</td>
    <td>Linear frequeny-modulation on 'Osc1 Out'</td>
    <td>measured or audible on 'Osc1 Out'.</td>
</tr>
<tr>
    <td>15</td>
    <td>Set switch 'FM1 Lin/Log' to 'FM1 Log' and detune VCO2 against VCO1</td>
    <td>Logarithmic frequeny-modulation on 'Osc1 Out'</td>
    <td>measured or audible on 'Osc1 Out'.</td>
</tr>
<tr>
    <td>16</td>
    <td>Set switch 'Sync Hard/Soft' to 'Sync Hard' and detune VCO2 against VCO1</td>
    <td>Hard synchronisation done between VCO2 and VCO1 forced by VCO2</td>
    <td>measured or audible on 'Osc1 Out'.</td>
</tr>
<tr>
    <td>17</td>
    <td>Set switch 'Sync Hard/Soft' to 'Sync Soft' and detune VCO2 against VCO1</td>
    <td>Soft synchronisation done between VCO2 and VCO1 forced by VCO2</td>
    <td>measured or audible on 'Osc1 Out'.</td>
</tr>
<tr>
    <td>18</td>
    <td>Set switch 'FM2 Lin/Log' to 'FM2 Lin' and change modulation-level with pot 'Mod.Level CV'</td>
    <td>Linear self frequeny-modulation on 'Osc2 Out' depending on modulation-level</td>
    <td>measured or audible on 'Osc2 Out'.</td>
</tr>
<tr>
    <td>19</td>
    <td>Set switch 'FM2 Lin/Log' to 'FM2 Log' and change modulation-level with pot 'Mod.Level CV'</td>
    <td>Logarithmic self frequeny-modulation on 'Osc2 Out' depending on modulation-level</td>
    <td>measured or audible on 'Osc2 Out'.</td>
</tr>
</table>

<hr> 

## License
> Hardware:cc by-nc-sa 4.0

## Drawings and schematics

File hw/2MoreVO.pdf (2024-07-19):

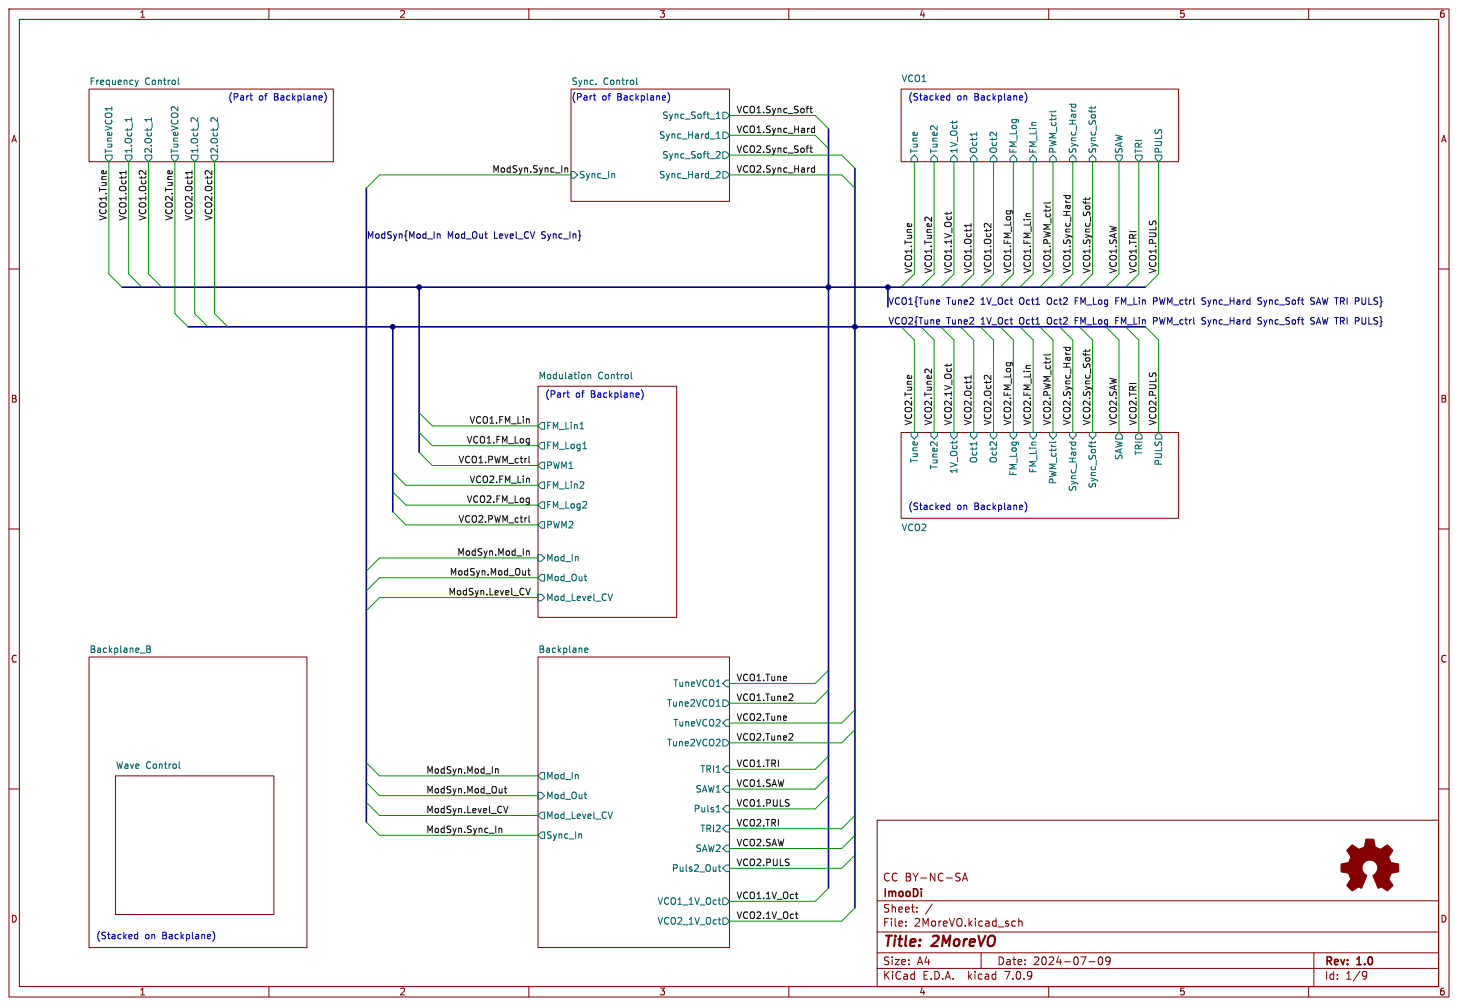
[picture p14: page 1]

VCO1{Tune Tune2 1V_Oct Oct1 Oct2 FM_Log FM_Lin PWM_ctrl Sync_Hard Sync_Soft SAW TRI PULS}
VCO2{Tune Tune2 1V_Oct Oct1 Oct2 FM_Log FM_Lin PWM_ctrl Sync_Hard Sync_Soft SAW TRI PULS}

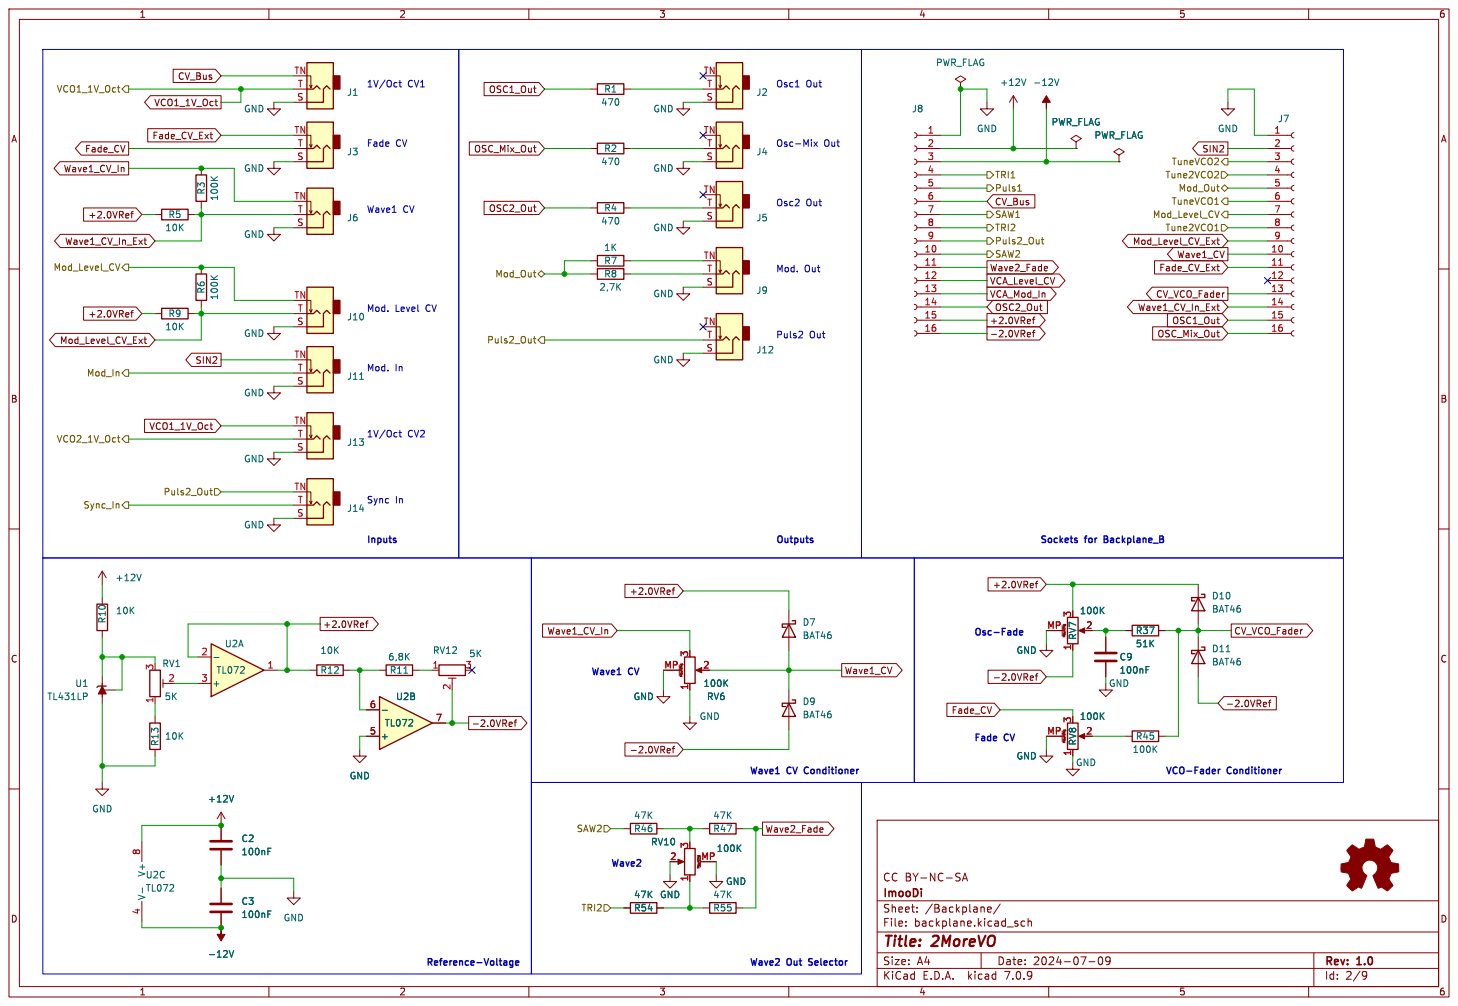
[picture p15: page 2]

TL072 GND GND GND GND

ImooDi CC BY-NC-SA

File: backplane.kicad_sch Sheet: /Backplane/
Id: 2/9 Title: 2MoreVO

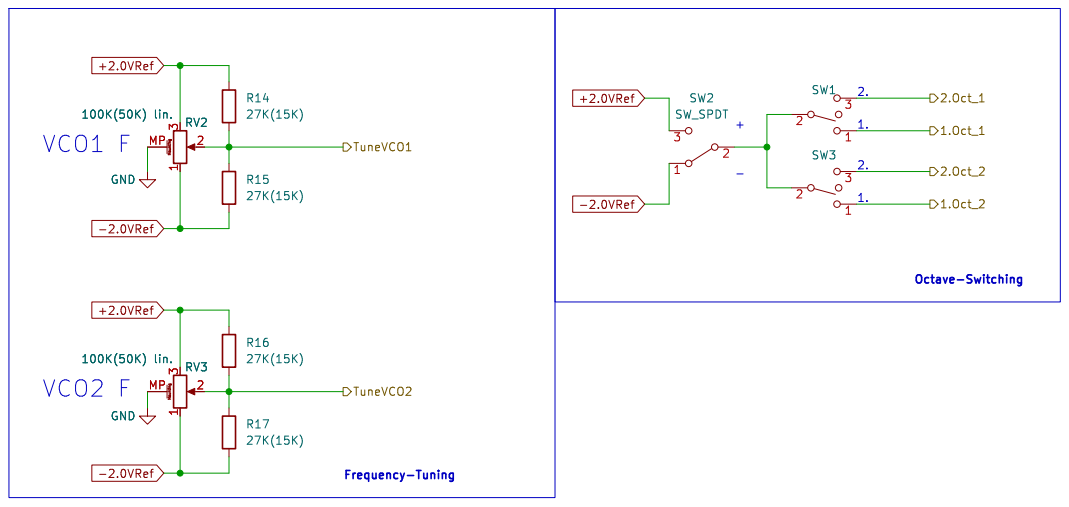
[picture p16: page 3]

ImooDi CC BY-NC-SA

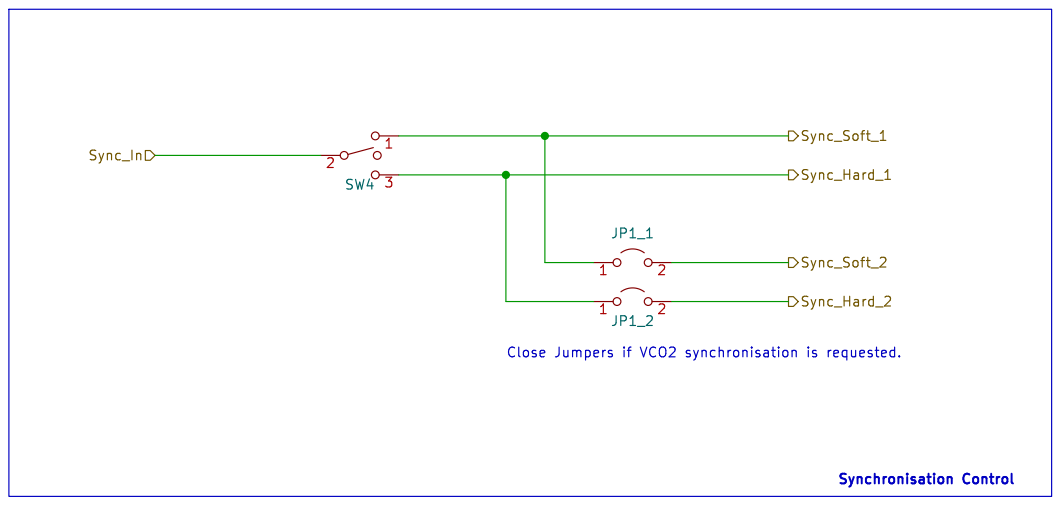
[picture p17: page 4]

ImooDi CC BY-NC-SA

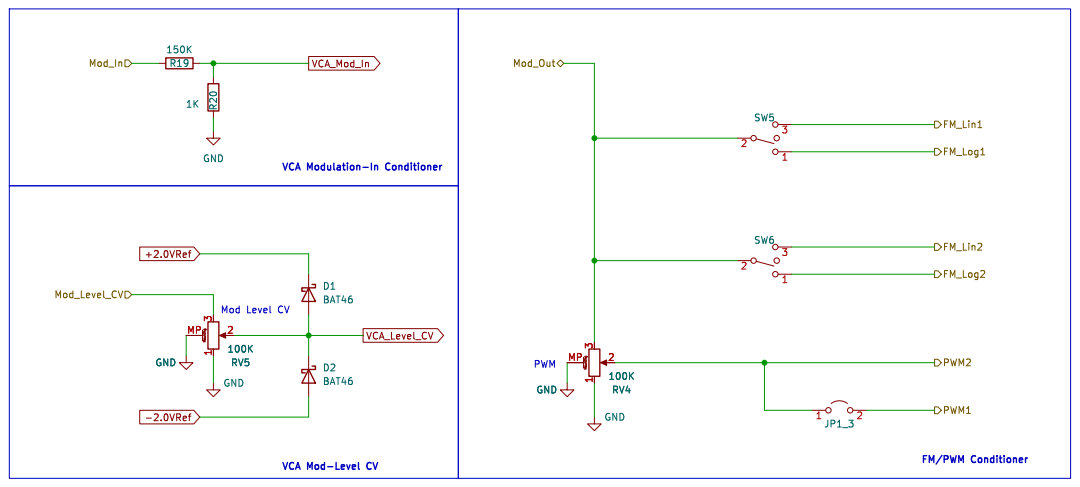
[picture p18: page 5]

ImooDi CC BY-NC-SA

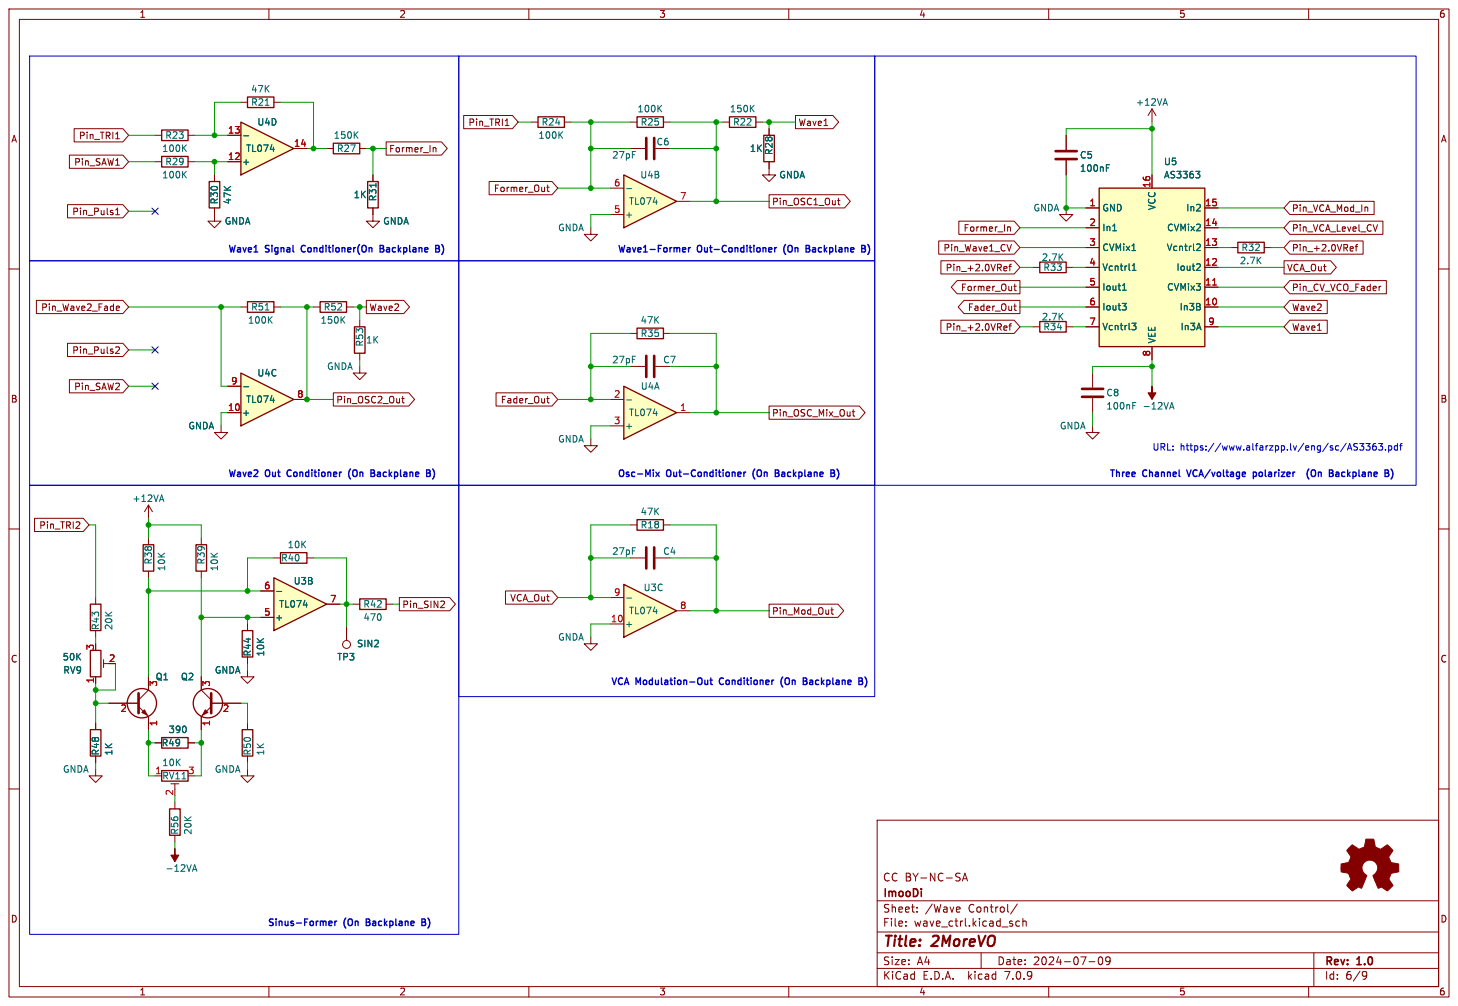
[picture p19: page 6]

ImooDi CC BY-NC-SA

File: wave_ctrl.kicad_sch Sheet: /Wave Control/
Id: 6/9 Title: 2MoreVO

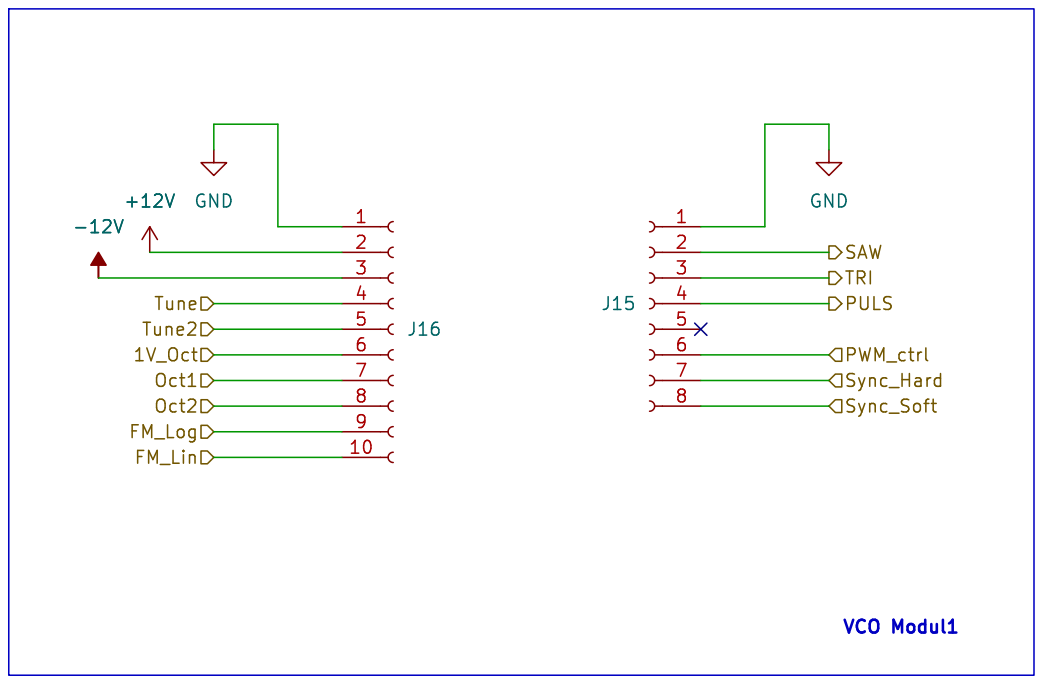
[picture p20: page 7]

ImooDi CC BY-NC-SA

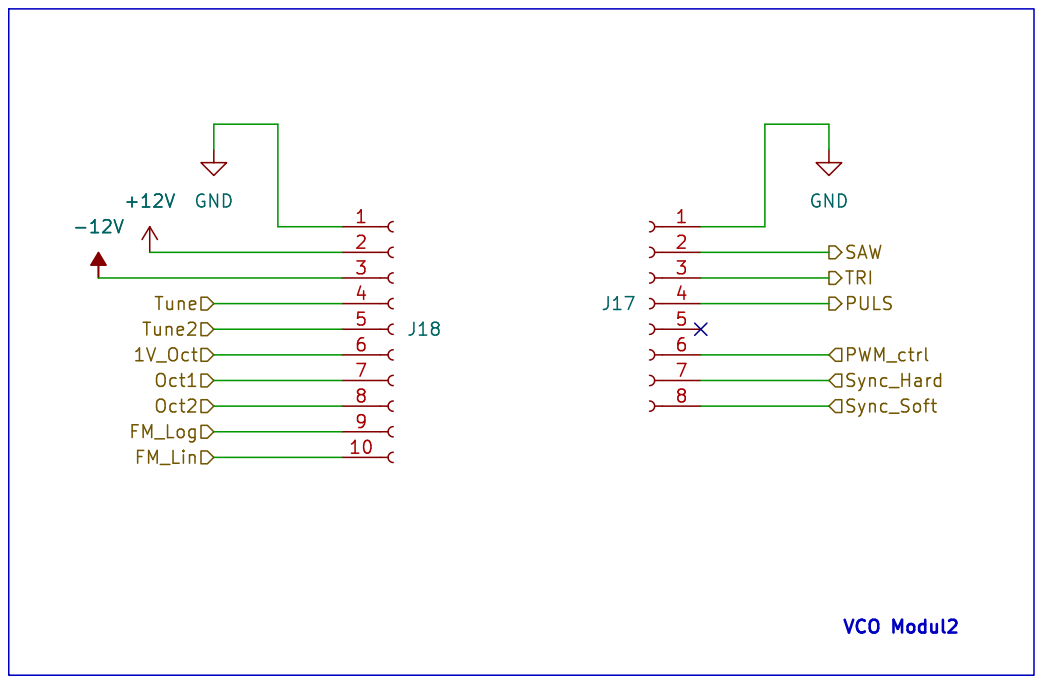
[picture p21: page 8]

ImooDi CC BY-NC-SA

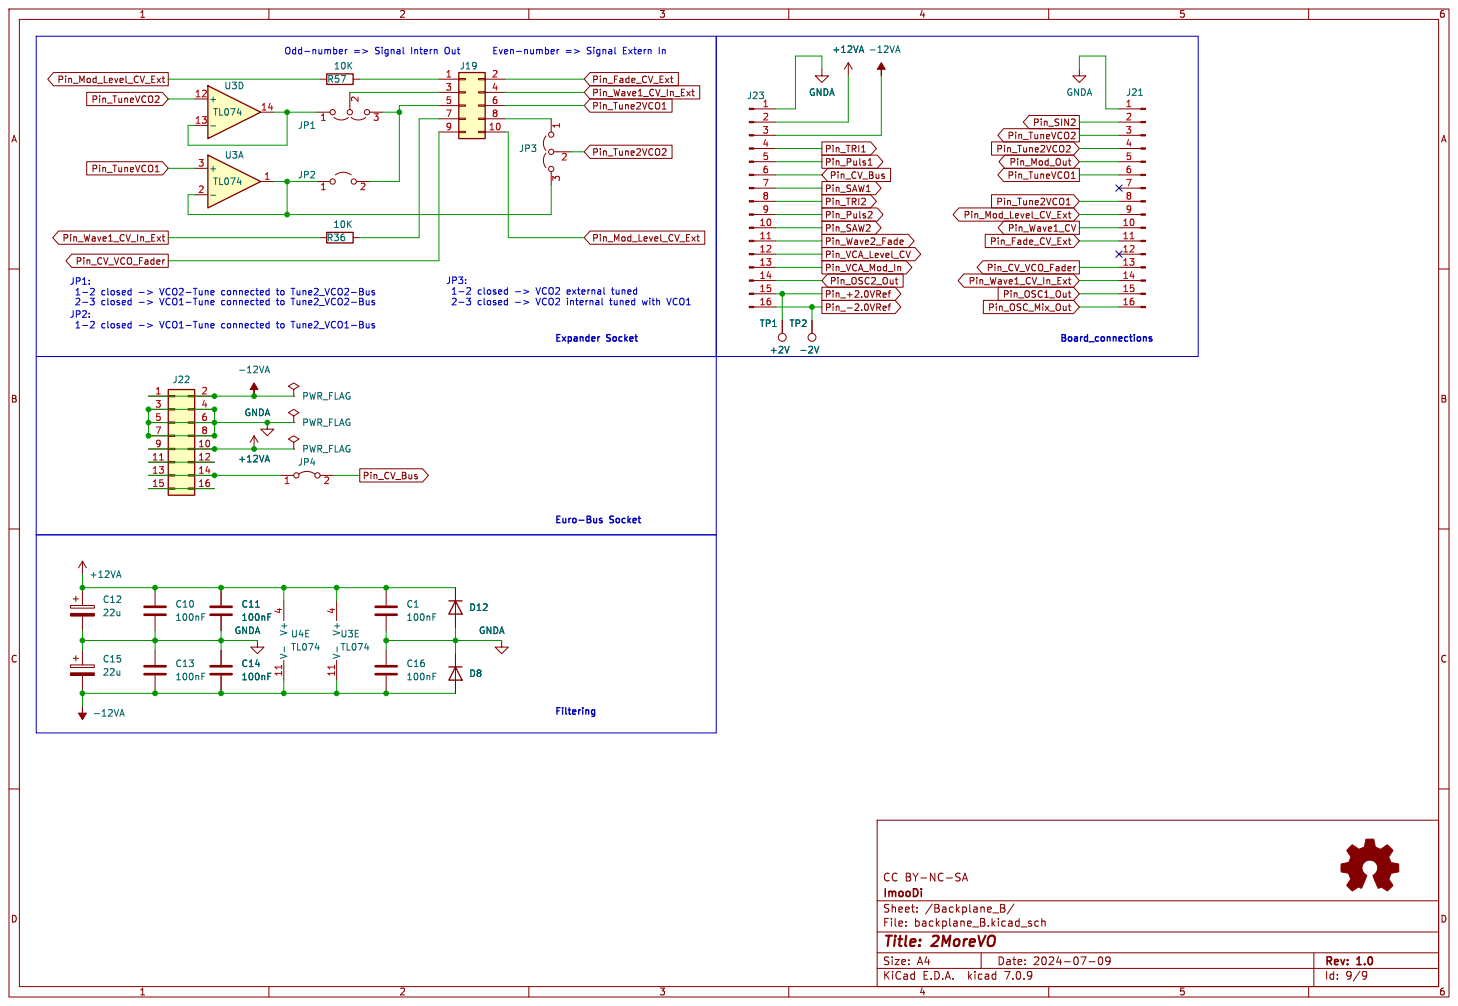
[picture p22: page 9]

ImooDi CC BY-NC-SA

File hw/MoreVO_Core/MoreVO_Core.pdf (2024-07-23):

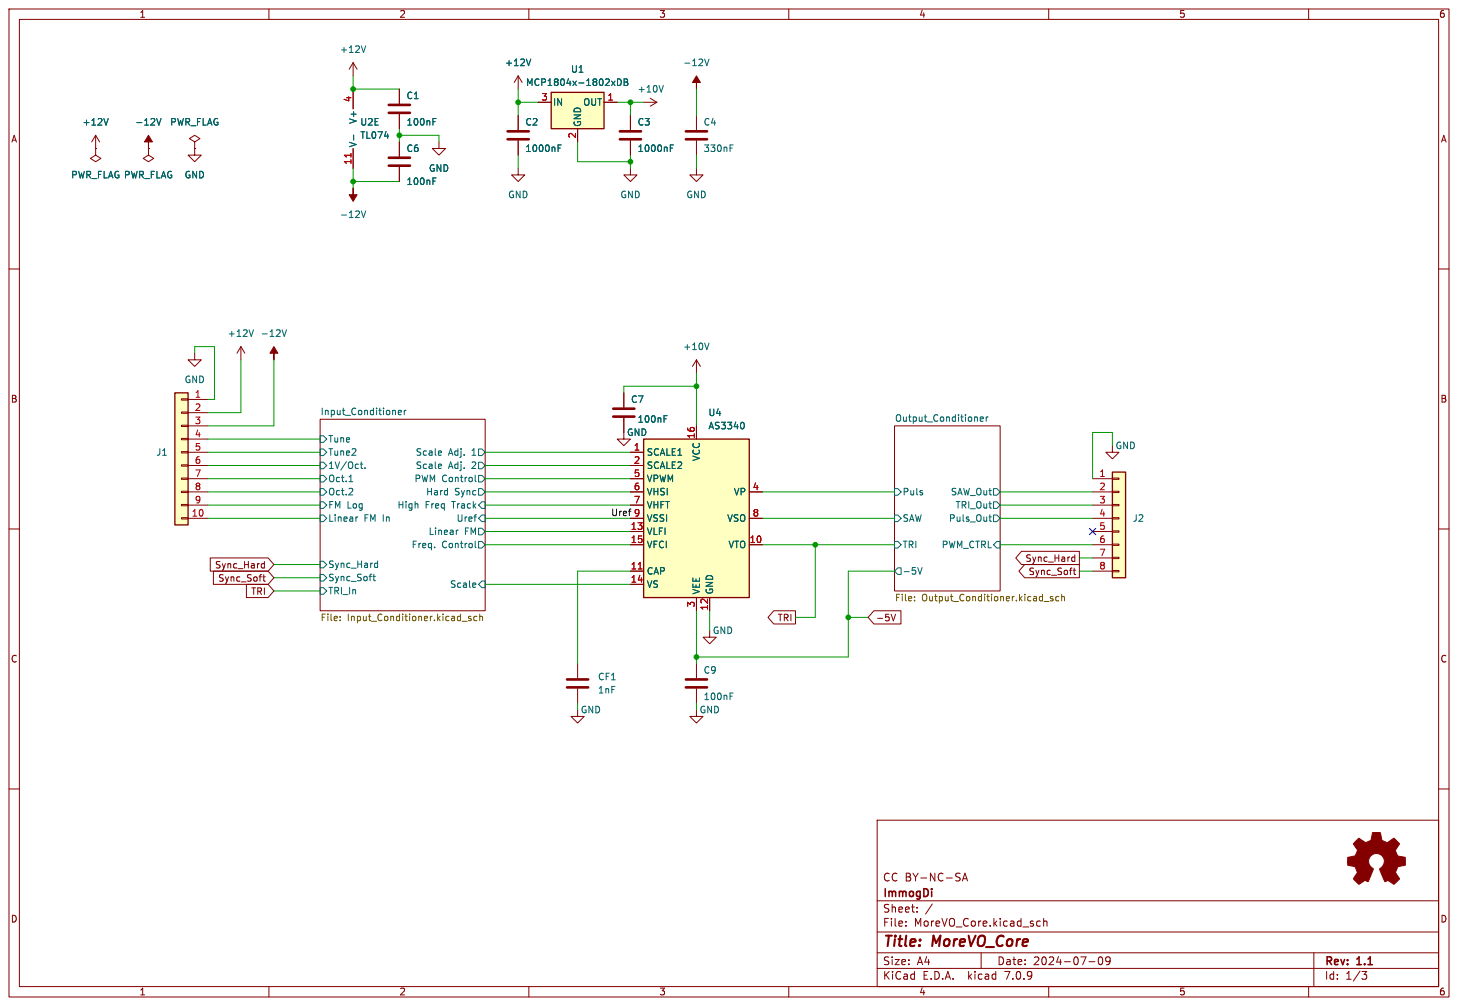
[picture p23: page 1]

3 VP 4 VPWM 5 VHSI 6 VHFT 7 VSO 8 VSSI 9 U4AS3340 C7

3 VP 4 VPWM 5 VHSI 6 VHFT 7 VSO 8 VSSI 9C7

Linear FM In Oct.2 Oct.1 Tune Tune2 FM Log

Freq. Control Scale High Freq Track Scale Adj. 1 Scale Adj. 2

ImmogDi CC BY-NC-SA

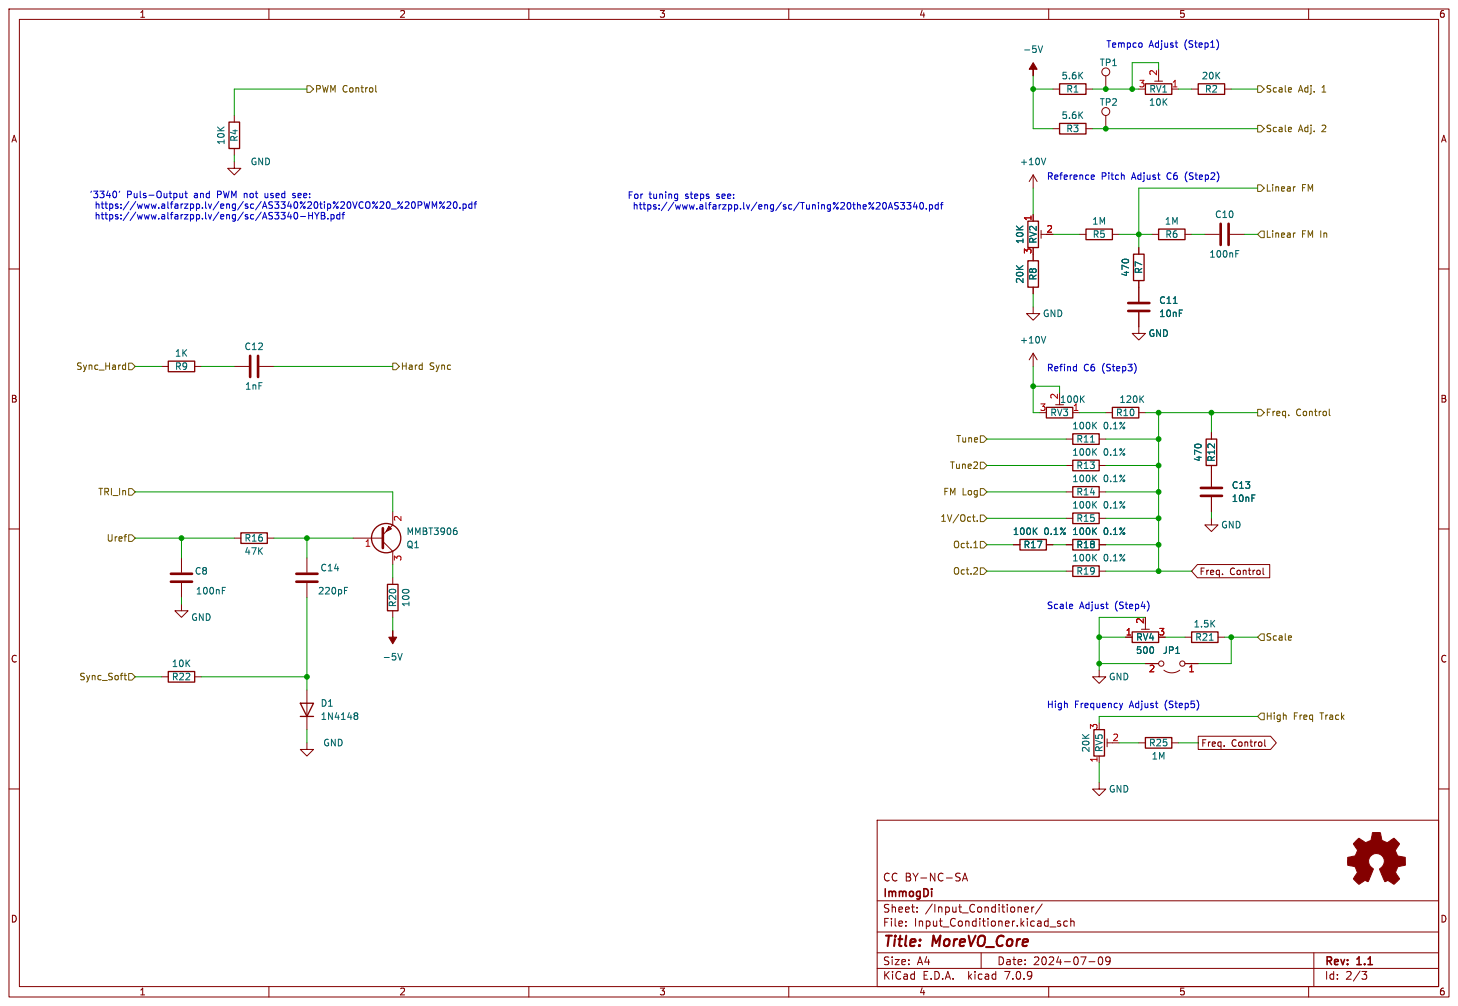
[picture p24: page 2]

ImmogDi CC BY-NC-SA

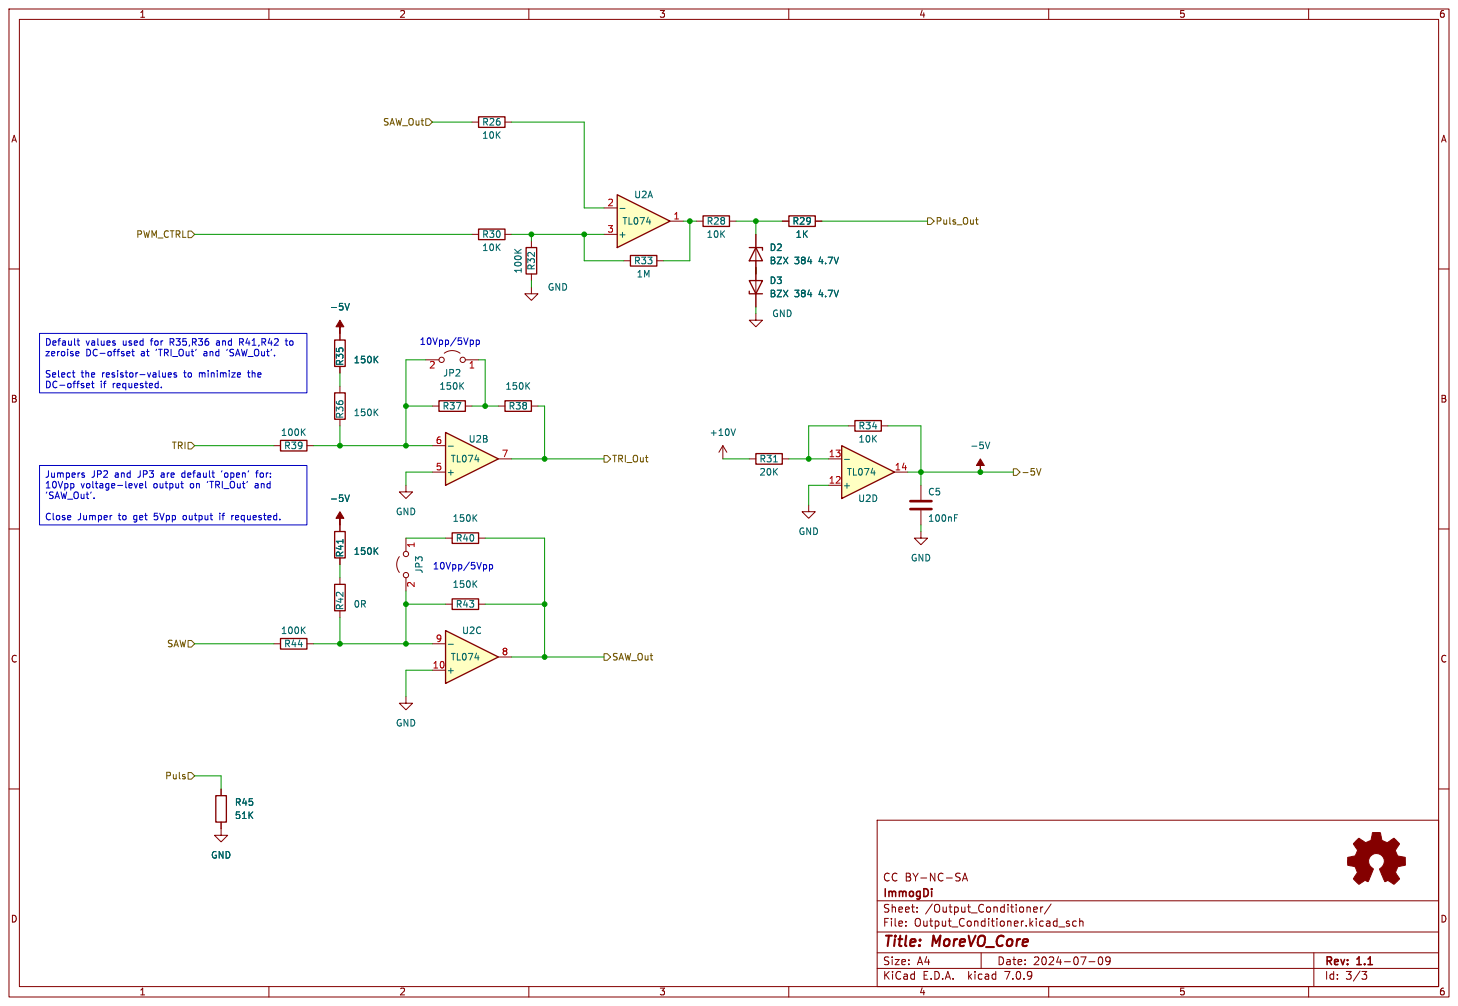
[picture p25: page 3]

'SAW_Out'. Close Jumper to get 5Vpp output if requested. Default values used for R35,R36 and R41,R42 to

ImmogDi CC BY-NC-SA

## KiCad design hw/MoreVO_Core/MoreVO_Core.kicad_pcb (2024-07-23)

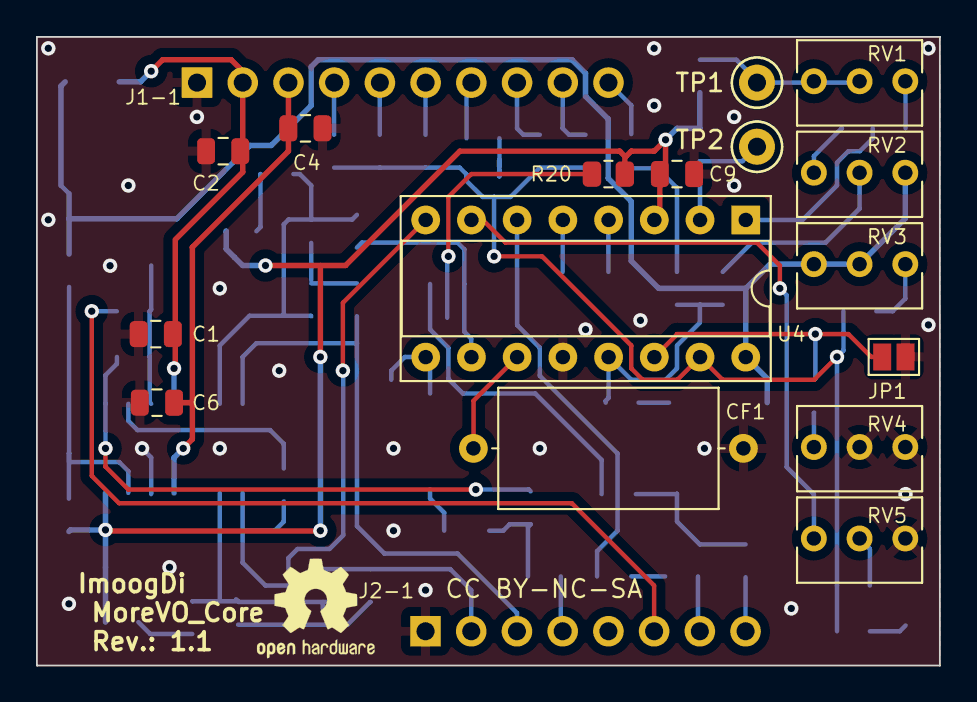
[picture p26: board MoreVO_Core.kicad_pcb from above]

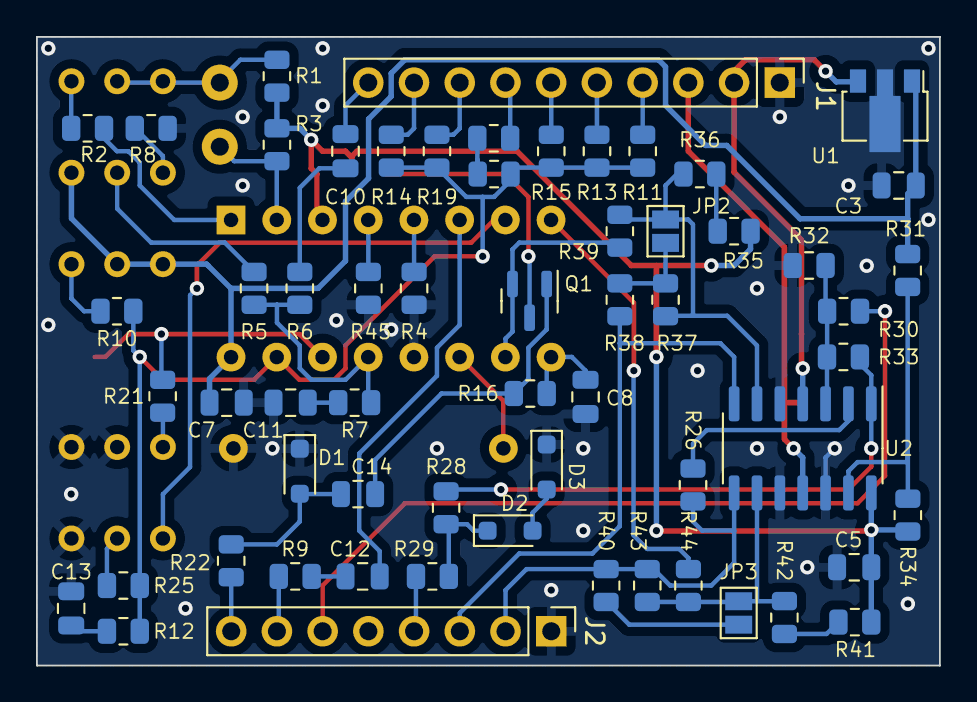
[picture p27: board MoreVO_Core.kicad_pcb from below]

Board: 2 copper layers, 50.2 x 34.9 mm, 76 parts (60 on the bottom side), 58 nets.

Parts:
C1, C5, C6, C7, C8, C9, C10: 100nF; C_0805_2012Metric
C2, C3: 1000nF; C_0805_2012Metric
C4: 330nF; C_0805_2012Metric
C11, C13: 10nF; C_0805_2012Metric
C12: 1nF; C_0805_2012Metric
C14: 220pF; C_0805_2012Metric
CF1: 1nF; C_Axial_L12.0mm_D6.5mm_P15.00mm_Horizontal
D1: 1N4148; D_SOD-323_HandSoldering
D2, D3: BZX 384 4.7V; D_SOD-323_HandSoldering
J1: Conn_01x10; PinHeader_1x10_P2.54mm_Vertical
J2: Conn_01x08; PinHeader_1x08_P2.54mm_Vertical
JP1, JP2, JP3: Jumper_2_Open; SolderJumper-2_P1.3mm_Open_Pad1.0x1.5mm
Q1: MMBT3906; SOT-23
R1, R3: 5.6K; R_0805_2012Metric
R2, R8, R31: 20K; R_0805_2012Metric
R4, R22, R26, R28, R30, R34: 10K; R_0805_2012Metric
R5, R6, R25, R33: 1M; R_0805_2012Metric
R7, R12: 470; R_0805_2012Metric
R9, R29: 1K; R_0805_2012Metric
R10: 120K; R_0805_2012Metric
R11, R13, R14, R15, R17, R18, R19: 100K 0.1%; R_0805_2012Metric
R16: 47K; R_0805_2012Metric
R20: 100; R_0805_2012Metric
R21: 1.5K; R_0805_2012Metric
R32, R39, R44: 100K; R_0805_2012Metric
R35, R36, R37, R38, R40, R41, R43: 150K; R_0805_2012Metric
R42: 0R; R_0805_2012Metric
R45: 51K; R_0805_2012Metric
RV1, RV2: 10K; Potentiometer_Bourns_3266Y_Vertical
RV3: 100K; Potentiometer_Bourns_3266Y_Vertical
RV4: 500; Potentiometer_Bourns_3266Y_Vertical
RV5: 20K; Potentiometer_Bourns_3266Y_Vertical
TP1, TP2: TestPoint; TestPoint_Keystone_5000-5004_Miniature
U1: MCP1804x-1802xDB; SOT-89-3
U2: TL074; SOIC-14_3.9x8.7mm_P1.27mm
U4: AS3340; DIP-16_W7.62mm_Socket

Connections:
+10V: C3.2, C7.2, R31.1, RV2.1, RV3.2, RV3.3, U1.1 (OUT), U4.16 (VCC)
+12V: C1.2, C2.2, J1.2, U1.3 (IN), U2.4 (V+)
-5V: C5.2, C9.2, R1.1, R3.1, R20.1, R34.2, R35.1, R41.1, U2.14, U4.3 (VEE)
-12V: C4.2, C6.1, J1.3, U2.11 (V-)
/Input_Conditioner/1V/Oct.: J1.6, R15.1
/Input_Conditioner/FM Log: J1.9, R14.1
/Input_Conditioner/Hard Sync: C12.2, U4.6 (VHSI)
/Input_Conditioner/High Freq Track: RV5.3, U4.7 (VHFT)
/Input_Conditioner/Linear FM: R5.2, R6.1, R7.2, U4.13 (VLFI)
/Input_Conditioner/Linear FM In: C10.2, J1.10
/Input_Conditioner/Oct.1: J1.7, R17.1
/Input_Conditioner/Oct.2: J1.8, R19.1
/Input_Conditioner/PWM Control: R4.2, U4.5 (VPWM)
/Input_Conditioner/Scale: JP1.1 (A), R21.2, U4.14 (VS)
/Input_Conditioner/Scale Adj. 1: R2.2, U4.1 (SCALE1)
/Input_Conditioner/Scale Adj. 2: R3.2, TP2.1, U4.2 (SCALE2)
/Input_Conditioner/Tune: J1.4, R11.1
/Input_Conditioner/Tune2: J1.5, R13.1
/Output_Conditioner/PWM_CTRL: J2.6, R30.1
/Output_Conditioner/Puls: R45.1, U4.4 (VP)
/Output_Conditioner/Puls_Out: J2.4, R29.2
/Output_Conditioner/SAW: R44.1, U4.8 (VSO)
/Output_Conditioner/SAW_Out: J2.2, R26.1, R40.2, R43.2, U2.8
/Output_Conditioner/TRI_Out: J2.3, R38.2, U2.7
/Uref: C8.2, R16.2, U4.9 (VSSI)
Freq. Control: R10.2, R11.2, R12.2, R13.2, R14.2, R15.2, R18.2, R19.2, R25.2, U4.15 (VFCI)
GND: C1.1, C2.1, C3.1, C4.1, C5.1, C6.2, C7.1, C8.1, C9.1, C11.1, C13.1, CF1.2, D1.1 (K), D3.1 (K), J1.1, J2.1, JP1.2 (B), R4.1, R8.1, R32.1, R45.2, RV4.1, RV4.2, RV5.1, U1.2 (GND), U2.5 (+), U2.10 (+), U2.12 (+), U4.12 (GND)
unnamed: C10.1, R6.2
unnamed: C11.2, R7.1
unnamed: C12.1, R9.2
unnamed: C13.2, R12.1
unnamed: C14.2, D1.2 (A), R22.2
unnamed: D2.2 (A), D3.2 (A)
unnamed: D2.1 (K), R28.2, R29.1
unnamed: JP2.1 (A), R37.2, R38.1
unnamed: JP2.2 (B), R36.2, R37.1, R39.2, U2.6 (-)
unnamed: JP3.1 (A), R40.1
unnamed: JP3.2 (B), R42.2, R43.1, R44.2, U2.9 (-)
unnamed: C14.1, Q1.1 (B), R16.1
unnamed: Q1.3 (C), R20.2
unnamed: R1.2, RV1.2, RV1.3, TP1.1
unnamed: R2.1, RV1.1
unnamed: R5.1, RV2.2
unnamed: R8.2, RV2.3
unnamed: R10.1, RV3.1
unnamed: R17.2, R18.1
unnamed: R21.1, RV4.3
unnamed: R25.1, RV5.2
unnamed: R28.1, R33.1, U2.1
unnamed: R35.2, R36.1
unnamed: R41.2, R42.1
unnamed: R30.2, R32.2, R33.2, U2.3 (+)
unnamed: R26.2, U2.2 (-)
unnamed: R31.2, R34.1, U2.13 (-)
unnamed: CF1.1, U4.11 (CAP)
Sync_Hard: J2.7, R9.1
Sync_Soft: J2.8, R22.1
TRI: Q1.2 (E), R39.1, U4.10 (VTO)

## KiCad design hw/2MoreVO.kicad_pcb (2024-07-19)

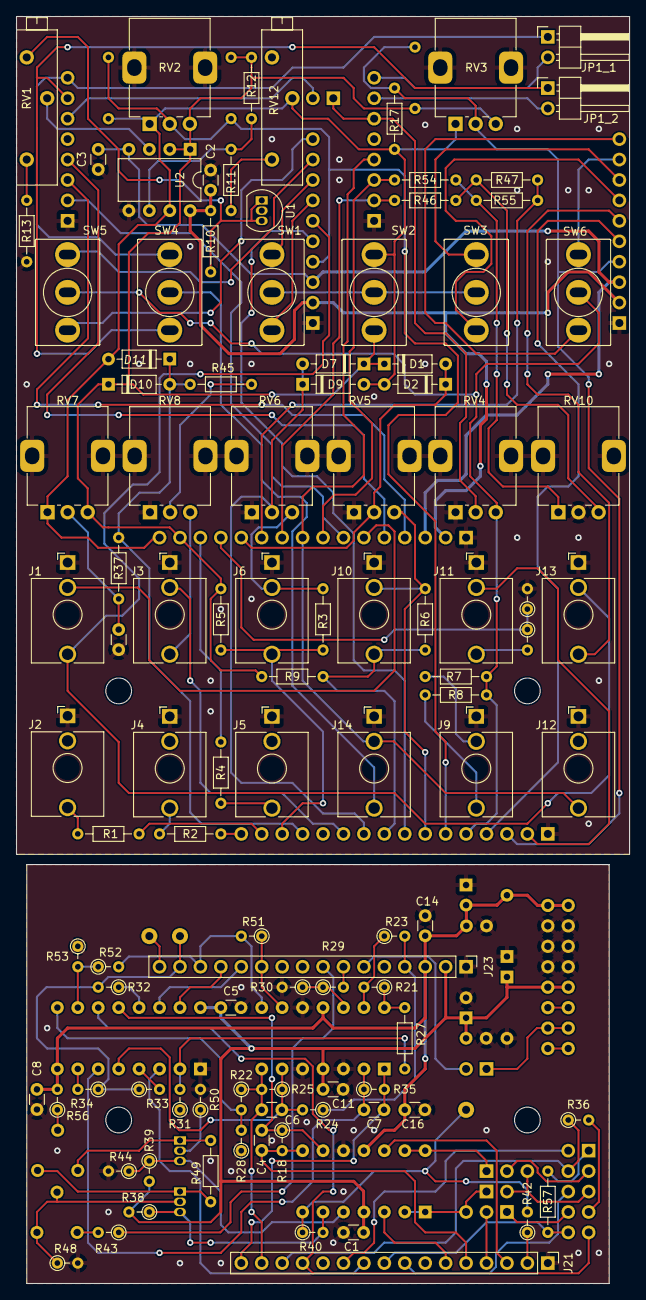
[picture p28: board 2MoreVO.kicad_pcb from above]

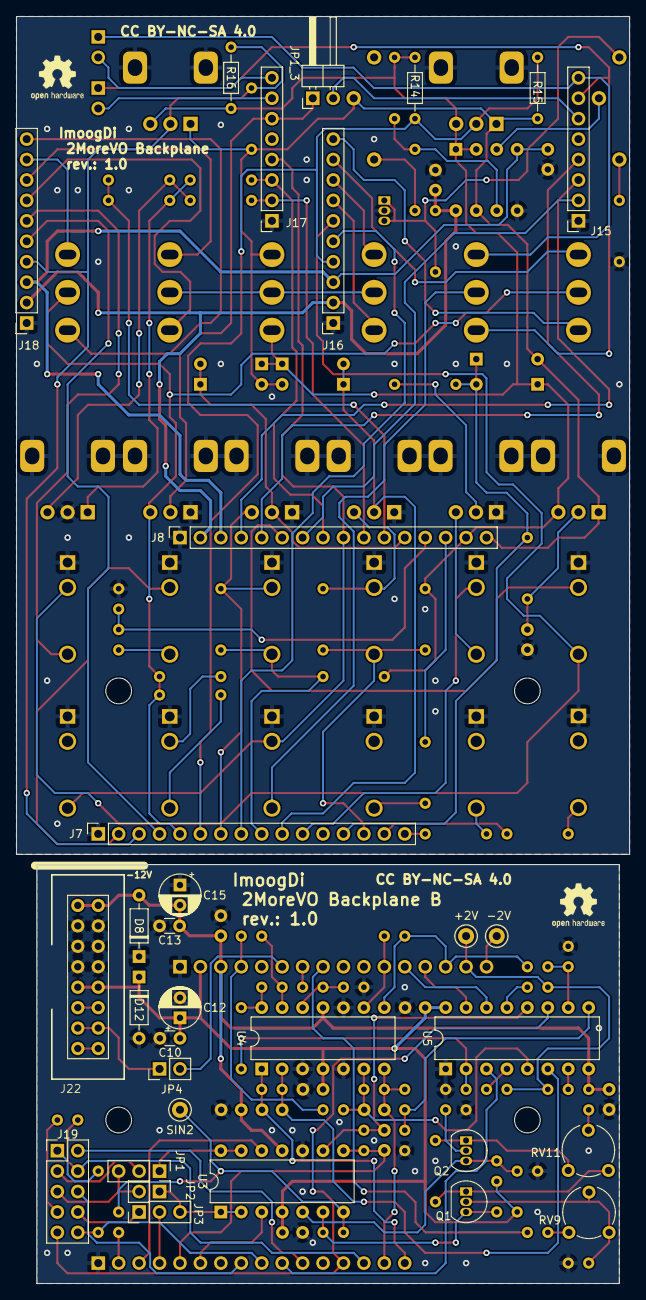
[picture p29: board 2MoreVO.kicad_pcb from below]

Board: 2 copper layers, 76.2 x 157.5 mm, 142 parts (34 on the bottom side), 122 nets.

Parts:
C1, C2, C3, C5, C8, C9, C10, C11, C13, C14, C16: 100nF; C_Disc_D3.0mm_W1.6mm_P2.50mm
C4, C6, C7: 27pF; C_Disc_D3.0mm_W1.6mm_P2.50mm
C12, C15: 22u; CP_Radial_D5.0mm_P2.50mm
D1, D2, D7, D9, D10, D11: BAT46; D_DO-35_SOD27_P7.62mm_Horizontal
D8, D12: 1N4001; D_DO-35_SOD27_P7.62mm_Horizontal
J1, J2, J3, J4, J5, J6, J9, J10, J11, J12, J13, J14: AudioJack2_SwitchT; Jack_3.5mm_QingPu_WQP-PJ398SM_Vertical_CircularHoles
J7, J8: Conn_01x16_Socket; PinSocket_1x16_P2.54mm_Vertical
J15, J17: Conn_01x08_Socket; PinSocket_1x08_P2.54mm_Vertical
J16, J18: Conn_01x10_Socket; PinSocket_1x10_P2.54mm_Vertical
J19: Conn_02x05_Odd_Even; PinHeader_2x05_P2.54mm_Vertical
J21, J23: Conn_01x16_Pin; PinHeader_1x16_P2.54mm_Vertical
J22: Conn_02x08_Odd_Even; Pins_2x08_2.54mm_TH_EuroPower_Shrouded_reducedsilk_pins_ass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
JP1, JP3: Jumper_3_Open; PinHeader_1x03_P2.54mm_Vertical
JP1_1, JP1_2, JP1_3: Jumper_2_Open; PinHeader_1x02_P2.54mm_Horizontal
JP2: Jumper_2_Open; PinHeader_1x02_P2.54mm_Vertical
JP4: Jumper_2_Bridged; PinHeader_1x02_P2.54mm_Vertical
Q1, Q2: 2N3904; TO-92_Inline
R1, R2, R4: 470; R_Axial_DIN0204_L3.6mm_D1.6mm_P7.62mm_Horizontal
R3, R6, R45: 100K; R_Axial_DIN0204_L3.6mm_D1.6mm_P7.62mm_Horizontal
R5, R9, R10, R12, R13, R57: 10K; R_Axial_DIN0204_L3.6mm_D1.6mm_P7.62mm_Horizontal
R7: 1K; R_Axial_DIN0204_L3.6mm_D1.6mm_P7.62mm_Horizontal
R8: 2,7K; R_Axial_DIN0204_L3.6mm_D1.6mm_P7.62mm_Horizontal
R11: 6,8K; R_Axial_DIN0204_L3.6mm_D1.6mm_P7.62mm_Horizontal
R14, R15, R16, R17: 27K(15K); R_Axial_DIN0204_L3.6mm_D1.6mm_P7.62mm_Horizontal
R18, R21, R30, R35: 47K; R_Axial_DIN0204_L3.6mm_D1.6mm_P2.54mm_Vertical
R19, R22, R52: 150K; R_Axial_DIN0204_L3.6mm_D1.6mm_P2.54mm_Vertical
R20, R28, R31, R48, R50, R53: 1K; R_Axial_DIN0204_L3.6mm_D1.6mm_P2.54mm_Vertical
R23, R24, R25, R29, R51: 100K; R_Axial_DIN0204_L3.6mm_D1.6mm_P2.54mm_Vertical
R27: 150K; R_Axial_DIN0204_L3.6mm_D1.6mm_P7.62mm_Horizontal
R32, R33, R34: 2.7K; R_Axial_DIN0204_L3.6mm_D1.6mm_P2.54mm_Vertical
R36, R38, R39, R40, R44: 10K; R_Axial_DIN0204_L3.6mm_D1.6mm_P2.54mm_Vertical
R37: 51K; R_Axial_DIN0204_L3.6mm_D1.6mm_P7.62mm_Horizontal
R42: 470; R_Axial_DIN0204_L3.6mm_D1.6mm_P2.54mm_Vertical
R43, R56: 20K; R_Axial_DIN0204_L3.6mm_D1.6mm_P2.54mm_Vertical
R46, R47, R54, R55: 47K; R_Axial_DIN0204_L3.6mm_D1.6mm_P7.62mm_Horizontal
R49: 390; R_Axial_DIN0204_L3.6mm_D1.6mm_P7.62mm_Horizontal
REF_A: OSHW-Logo2_7.3x6mm_SilkScreen
REF_B: OSHW-Logo2_7.3x6mm_SilkScreen
REF_L1, REF_L2, REF_L3, REF_L4: MountingHole_3.2mm_M3
RV1, RV12: 5K; Potentiometer_Bourns_3006P_Horizontal
RV2, RV3: 100K(50K) lin.; Potentiometer_Alps_RK09K_Single_Vertical
RV4, RV5, RV6, RV7, RV8, RV10: 100K; Potentiometer_Alps_RK09K_Single_Vertical
RV9: 50K; Potentiometer_Piher_PT-6-V_Vertical
RV11: 10K; Potentiometer_Piher_PT-6-V_Vertical
SW1, SW3, SW4, SW5, SW6: SW_SPDT_MSM; Switch_Toggle_SPDT_Mini_SolderLug
SW2: SW_SPDT; Switch_Toggle_SPDT_Mini_SolderLug
TP1: +2V; TestPoint_Keystone_5000-5004_Miniature
TP2: -2V; TestPoint_Keystone_5000-5004_Miniature
TP3: SIN2; TestPoint_Keystone_5000-5004_Miniature
U1: TL431LP; TO-92_Inline
U2: TL072; DIP-8_W7.62mm
U3, U4: TL074; DIP-14_W7.62mm
U5: AS3363; DIP-16_W7.62mm

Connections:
+2.0VRef: D1.1 (K), D7.1 (K), D10.1 (K), J8.15, R5.2, R9.2, R12.1, R14.1, R16.1, RV2.3, RV3.3, RV7.3, SW2.3 (C), U2.1, U2.2 (-)
+12V: C2.1, J8.2, J16.2, J18.2, R10.1, U2.8 (V+)
+12VA: C1.1, C5.1, C10.1, C11.1, C12.1, D12.1 (K), J22.9, J22.10, J23.2, R38.2, R39.2, U3.4 (V+), U4.4 (V+), U5.16 (VCC)
-2.0VRef: D2.2 (A), D9.2 (A), D11.2 (A), J8.16, R15.2, R17.2, RV2.1, RV3.1, RV7.1, RV12.2, SW2.1 (A), U2.7
-12V: C3.2, J8.3, J16.3, J18.3, U2.4 (V-)
-12VA: C8.1, C13.2, C14.2, C15.2, C16.2, D8.2 (A), J22.1, J22.2, J23.3, R56.2, U3.11 (V-), U4.11 (V-), U5.8 (VEE)
/ModSyn.Level_CV: J7.7, J10.TN, R6.1, RV5.3
/ModSyn.Mod_In: J11.T, R19.2
/ModSyn.Mod_Out: J7.5, R7.1, R8.1, RV4.3, SW5.2, SW6.2
/ModSyn.Sync_In: J14.T, SW4.2
/VCO1.FM_Lin: J16.10, SW5.3
/VCO1.FM_Log: J16.9, SW5.1
/VCO1.Oct1: J16.7, SW1.1
/VCO1.Oct2: J16.8, SW1.3
/VCO1.PULS: J8.5, J15.4
/VCO1.PWM_ctrl: J15.6, JP1_3.2 (B)
/VCO1.SAW: J8.7, J15.2
/VCO1.Sync_Hard: J15.7, JP1_2.1 (A), SW4.3
/VCO1.Sync_Soft: J15.8, JP1_1.1 (A), SW4.1
/VCO1.TRI: J8.4, J15.3
/VCO1.Tune: J7.6, J16.4, R14.2, R15.1, RV2.2
/VCO1.Tune2: J7.8, J16.5
/VCO2.1V_Oct: J13.T, J18.6
/VCO2.FM_Lin: J18.10, SW6.3
/VCO2.FM_Log: J18.9, SW6.1
/VCO2.Oct1: J18.7, SW3.1
/VCO2.Oct2: J18.8, SW3.3
/VCO2.PULS: J8.9, J12.T, J14.TN, J17.4
/VCO2.PWM_ctrl: J17.6, JP1_3.1 (A), RV4.2
/VCO2.SAW: J8.10, J17.2, R46.1
/VCO2.Sync_Hard: J17.7, JP1_2.2 (B)
/VCO2.Sync_Soft: J17.8, JP1_1.2 (B)
/VCO2.TRI: J8.8, J17.3, R54.1
/VCO2.Tune: J7.3, J18.4, R16.2, R17.1, RV3.2
/VCO2.Tune2: J7.4, J18.5
CV_Bus: J1.TN, J8.6
CV_VCO_Fader: D10.2 (A), D11.1 (K), J7.13, R37.1, R45.1
Fade_CV: J3.T, RV8.3
Fade_CV_Ext: J3.TN, J7.11
Fader_Out: C7.1, R35.1, U4.2 (-), U5.6 (Iout3)
Former_In: R27.2, R31.2, U5.2 (In1)
Former_Out: C6.1, R24.2, R25.1, U4.6 (-), U5.5 (Iout1)
GND: C2.2, C3.1, C9.2, J1.S, J2.S, J3.S, J4.S, J5.S, J6.S, J7.1, J8.1, J9.S, J10.S, J11.S, J12.S, J13.S, J14.S, J15.1, J16.1, J17.1, J18.1, R13.1, R20.2, RV2.MP (MountPin), RV3.MP (MountPin), RV4.1, RV4.MP (MountPin), RV5.1, RV5.MP (MountPin), RV6.1, RV6.MP (MountPin), RV7.MP (MountPin), RV8.1, RV8.MP (MountPin), RV10.2, RV10.MP (MountPin), U1.2 (A), U2.5 (+)
GNDA: C1.2, C5.2, C8.2, C10.2, C11.2, C12.2, C13.1, C14.1, C15.1, C16.1, D8.1 (K), D12.2 (A), J21.1, J22.3, J22.4, J22.5, J22.6, J22.7, J22.8, J23.1, R28.1, R30.2, R31.1, R44.2, R48.2, R50.2, R53.1, U3.10 (+), U4.3 (+), U4.5 (+), U4.10 (+), U5.1 (GND)
Mod_Level_CV_Ext: J7.9, J10.T, R6.2, R9.1
unnamed: C9.1, R37.2, RV7.2
unnamed: J2.T, R1.1
unnamed: J4.T, R2.1
unnamed: J5.T, R4.1
unnamed: J9.T, R8.2
unnamed: J9.TN, R7.2
unnamed: J19.1, R57.1
unnamed: J19.3, JP1.2 (C)
unnamed: J19.5, JP1.3 (B), JP2.2 (B)
unnamed: J19.7, R36.2
unnamed: J19.8, JP3.1 (A)
unnamed: J22.11, J22.12
unnamed: J22.13, J22.14, JP4.1 (A)
unnamed: J22.15, J22.16
unnamed: JP1.1 (A), U3.13 (-), U3.14
unnamed: JP2.1 (A), JP3.3 (B), U3.1, U3.2 (-)
unnamed: Q1.2 (B), R48.1, RV9.1, RV9.2
unnamed: Q1.3 (C), R38.1, R40.2, U3.6 (-)
unnamed: Q1.1 (E), R49.1, RV11.1
unnamed: Q2.2 (B), R50.1
unnamed: Q2.3 (C), R39.1, R44.1, U3.5 (+)
unnamed: Q2.1 (E), R49.2, RV11.3
unnamed: R11.2, RV12.1
unnamed: R13.2, RV1.1
unnamed: R21.1, R27.1, U4.14
unnamed: R40.1, R42.2, TP3.1, U3.7
unnamed: R43.2, RV9.3
unnamed: R45.2, RV8.2
unnamed: R46.2, R47.1, RV10.3
unnamed: R54.2, R55.1, RV10.1
unnamed: R56.1, RV11.2
unnamed: SW1.2, SW2.2 (B), SW3.2
unnamed: R10.2, RV1.3, U1.1 (REF), U1.3 (K)
unnamed: RV1.2, U2.3 (+)
unnamed: R11.1, R12.2, U2.6 (-)
unnamed: R29.1, R30.1, U4.12 (+)
unnamed: R21.2, R23.1, U4.13 (-)
unnamed: R33.2, U5.4 (Vcntrl1)
unnamed: R32.1, U5.13 (Vcntrl2)
unnamed: R34.2, U5.7 (Vcntrl3)
OSC1_Out: J7.15, R1.2
OSC2_Out: J8.14, R4.2
OSC_Mix_Out: J7.16, R2.2
Pin_+2.0VRef: J23.15, R32.2, R33.1, R34.1, TP1.1
Pin_-2.0VRef: J23.16, TP2.1
Pin_CV_Bus: J23.6, JP4.2 (B)
Pin_CV_VCO_Fader: J19.9, J21.13, U5.11 (CVMix3)
Pin_Fade_CV_Ext: J19.2, J21.11
Pin_Mod_Level_CV_Ext: J19.10, J21.9, R57.2
Pin_Mod_Out: C4.2, J21.5, R18.2, U3.8
Pin_OSC1_Out: C6.2, J21.15, R22.1, R25.2, U4.7
Pin_OSC2_Out: J23.14, R51.2, R52.2, U4.8
Pin_OSC_Mix_Out: C7.2, J21.16, R35.2, U4.1
Pin_SAW1: J23.7, R29.2
Pin_SIN2: J21.2, R42.1
Pin_TRI1: J23.4, R23.2, R24.1
Pin_TRI2: J23.8, R43.1
Pin_Tune2VCO1: J19.6, J21.8
Pin_Tune2VCO2: J21.4, JP3.2 (C)
Pin_TuneVCO1: J21.6, U3.3 (+)
Pin_TuneVCO2: J21.3, U3.12 (+)
Pin_VCA_Level_CV: J23.12, U5.14 (CVMix2)
Pin_VCA_Mod_In: J23.13, U5.15 (In2)
Pin_Wave1_CV: J21.10, U5.3 (CVMix1)
Pin_Wave1_CV_In_Ext: J19.4, J21.14, R36.1
Pin_Wave2_Fade: J23.11, R51.1, U4.9 (-)
SIN2: J7.2, J11.TN
VCA_Level_CV: D1.2 (A), D2.1 (K), J8.12, RV5.2
VCA_Mod_In: J8.13, R19.1, R20.1
VCA_Out: C4.1, R18.1, U3.9 (-), U5.12 (Iout2)
VCO1_1V_Oct: J1.T, J13.TN, J16.6
Wave1: R22.2, R28.2, U5.9 (In3A)
Wave1_CV: D7.2 (A), D9.1 (K), J7.10, RV6.2
Wave1_CV_In: J6.TN, R3.1, RV6.3
Wave1_CV_In_Ext: J6.T, J7.14, R3.2, R5.1
Wave2: R52.1, R53.2, U5.10 (In3B)
Wave2_Fade: J8.11, R47.2, R55.2

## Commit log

2024-07-19 Add files via upload
    2MoreVO; rev: 1.0
    [2MoreVO.kicad_pcb, 2MoreVO.kicad_sch, backplane.kicad_sch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]
2024-07-23 Add files via upload
    MoreVO_Core rev.: 1.1 added
    [Input_Conditioner.kicad_sch, MoreVO_Core.kicad_pcb, MoreVO_Core.kicad_sch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]
2024-07-24 Add files via upload
    MoreVO_Core PCB pictures added.
2024-08-10 doc-calibration update
